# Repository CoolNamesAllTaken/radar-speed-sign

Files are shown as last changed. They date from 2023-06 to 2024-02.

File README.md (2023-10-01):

# radar-speed-sign
How much zoom is too much zoom?

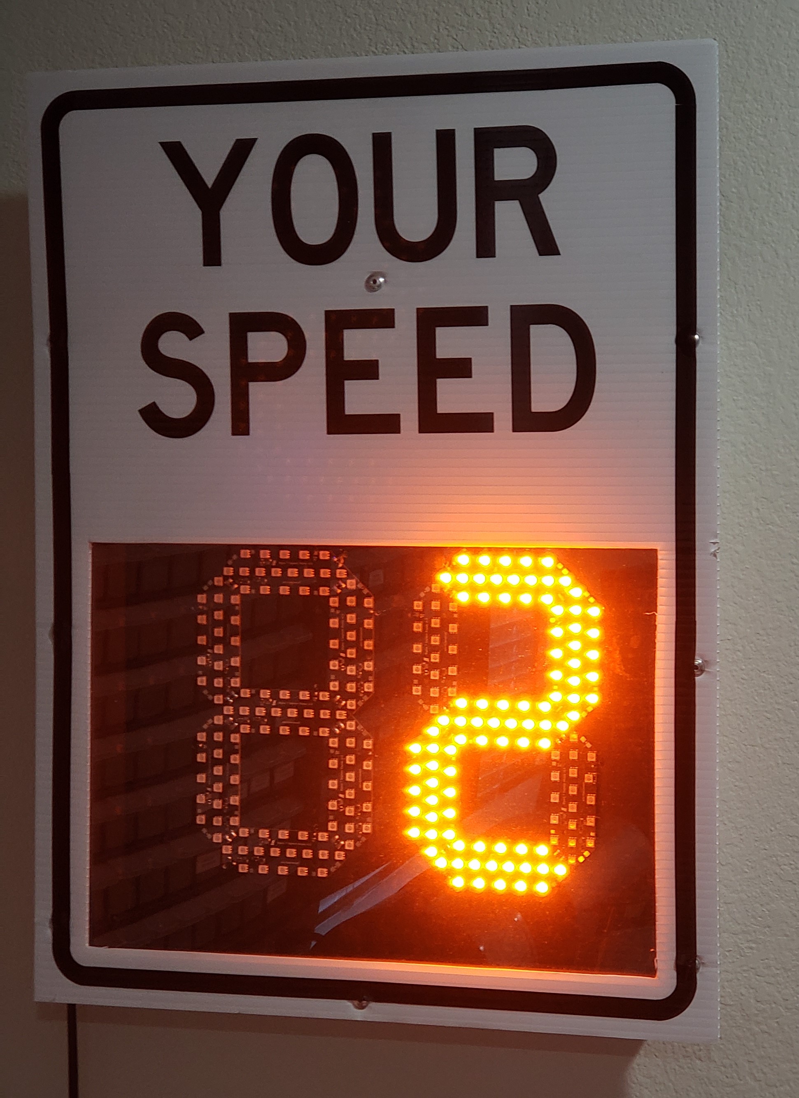
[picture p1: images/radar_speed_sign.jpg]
Radar speed sign mounted to my wall


This is a DIY radar speed sign based on an HB100 doppler radar sensor and a cheap microcontroller (originally an Arduino Nano, now a Pi Pico). The detection range with the stock HB100 antenna is too short for reading speeds of cars, but works well for pedestrians at close range!

This repository includes firmware for both the original project, which used Arduino (C++), and the updated kit version of the project, which runs MicroPython on a Pi Pico. PCB design and fabrication files are also included. Have fun!

[Project Writeup](https://johnmcnelly.com/arduino-radar-speed-sign/)

[Electronics Kit Store Link](https://pantsforbirds.com/product/radar-speed-sign/)

## Software (Python)
Note: Radar speed sign kits ship with a Pi Pico that has been pre-flashed with MicroPython and the latest version of the Pico Radar Speed Sign firmware. Follow the instructions below for updating to new versions of the Pico Radar Speed Sign firmeware or for flashing a Pi Pico from scratch.

### Setting up MicroPython
First time setup with a blank Pi Pico? Follow [these instructions](https://www.raspberrypi.com/documentation/microcontrollers/micropython.html)!

### Updating Firmware
Firmware in the `code/pico_radar_speed_sign` directory can be uploaded to the Pi Pico using Thonny or the [Pico W-Go Extension](https://github.com/paulober/MicroPico) for VSCode. If uploading code using VSCode, open the `code/pico_radar_speed_sign` directory with VSCode in order to automatically use the settings configured in the `.vscode` directory and the `.micropico` file.

## Software (Arduino C++)
The original radar speed sign used code written in Arduino C++. This can be found in the `code/radar_speed_sign` directory, and is intended to be edited using the PlatformIO extension for VSCode.

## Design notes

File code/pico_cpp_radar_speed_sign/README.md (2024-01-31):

# Overview

This folder includes code used for programming the Pi Pico radar speed sign using C++ and the Pico SDK, which enables more advanced functionarlity than can be achieved when programming with MicroPython.

Compilation is done in the included docker environment, and debugging is currently set up to work with a J-Link debugger peripheral via the J-Link GDB Server application.

# Getting Started

1. Initialize git submodules with `git submodule update --recursive --remote`.
2. Build the development docker container with `docker build -t pico_cpp_radar_speed_sign .` from this folder.

### Run the Docker Container

`docker compose up`

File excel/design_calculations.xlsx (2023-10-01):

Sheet: Bigass LED Calculations
Parameter | Value | Unit | Note
5050 LED Module
V_f,LED | 2 | V | Typical forward voltage of LED module.
I_f,LED,channel | 40 | mA | Typical forward current of single channel on LED module with V_f = V_f,LED.
I_f,LED | 120 | mA
Current Limiting Resistor
I_CLR | 120 | mA
V_CLR | 0.5 | V
R_CLR | 4.2 | Ohms
P_CLR,max | 0.1 | W
P_CLR | 0.06 | W | Cross-check power dissipated to make sure It’s within the limit.
NPN Transistor |  |  | https://datasheet.lcsc.com/lcsc/2303221100_Jiangsu-Changjing-Electronics-Technology-Co---Ltd--SS8050_C2150.pdf
I_c | 360 | mA | Collector current from all LED strings.
V_be,sat | 0.8 | V | Base-emitter voltage at I_c. Taken conservatively from datasheet for higher junction temperature.
h_fe | 200 |  | DC Current Gain at I_c.
I_b | 1.8 | mA
V_drive | 3.3 | V | Drive voltage used for speccing base resistor.
R_b | 1.39 | kOhms

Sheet: Pico Board Calculations
Parameter | Value | Unit | Note
V_out | 5 | V
V_fb | 1.23 | V
R_bot | 10 | kOhms |  | V_fb = V_out*(R_bot/(R_bot+R_top))
R_top | 30.7 | kOhms |  | V_fb*(R_bot+R_top) = V_out*R_bot
 |  |  |  | R_top = (V_out-V_fb)*R_bot/V_fb
 |  |  |  | R_top = (V_out/V_fb-1)*R_bot

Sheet: Horn Antenna
Parameter | Value | Units | Note
Near Field
c = f*lambda
d_k | 1 |  | Dielectric constant.
f | 20 | GHz
lambda | 15 | mm | One wavelength. Everything closer than this is pretty much in the near field of the antenna and may affect its tuning.
Nickel Plating Cost Calculator
A_panel | 3232.62 | mm^2 | Surface area of a single side panel.
 | 32.3262 | cm^2
A_total | 258.6096 | cm^2
Plating Thickness | 5 | um
Plating Time | 11.81 | min
Nickel Debits | 473.4388346
One-Plate Solution Volume | 77.86822938 | mL
One-Plate Solution Cost/mL | 0.04755813953
Plating Solution Cost | $3.70

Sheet: Radar Calibration
Parameter | Value | Value | Value | Value | Unit | Note
f | 10.525 | 10.525 | 10.525 | 10.525 | GHz
lambda | 28.50356295 | 28.50356295 | 28.50356295 | 28.50356295 | mm | Wavelength.
V | 1 | 5 | 35 | 95 | mph |  | https://wx.erau.edu/faculty/mullerb/Wx365/Doppler_formulas/doppler_formulas.pdf
V | 0.44704 | 2.2352 | 15.6464 | 42.4688 | m/s
f_d | 31.36730667 | 156.8365333 | 1097.855733 | 2979.894133 | Hz | Doppler shift frequency.

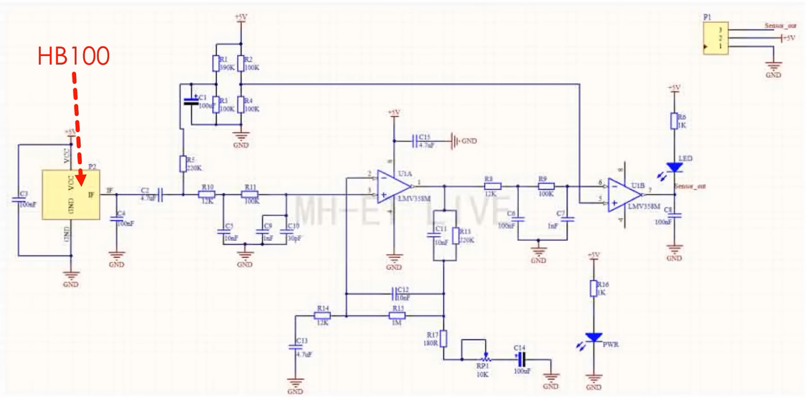
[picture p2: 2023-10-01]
references/HB100X_Schematic_Screenshot.png

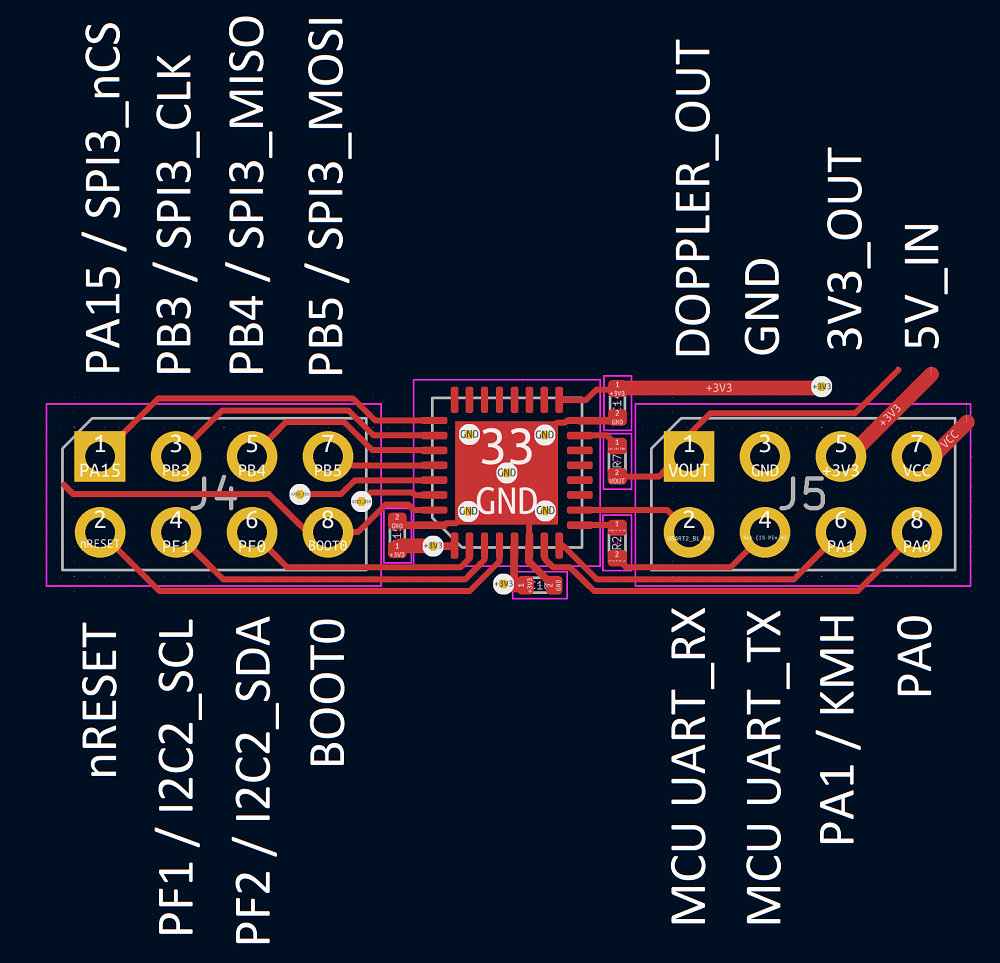
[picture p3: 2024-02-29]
references/CDM324 Doppler Speed Sensor, with FFTs! - Limpkin's blog_files/exp_pinout.png

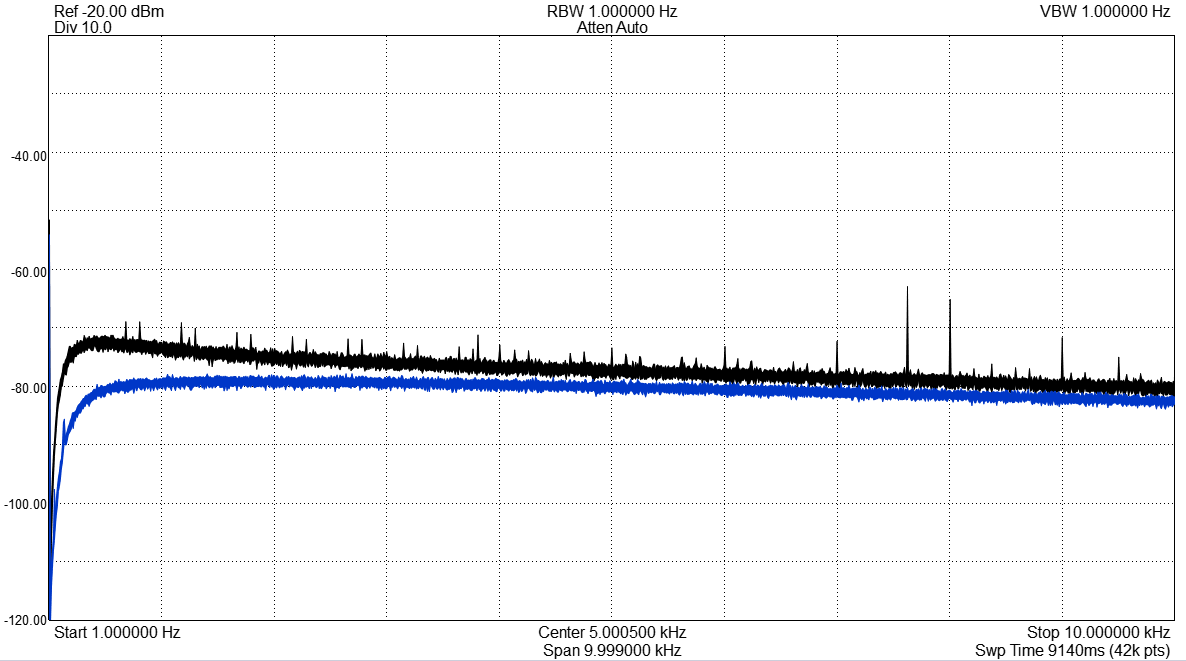
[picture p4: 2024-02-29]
references/CDM324 Doppler Speed Sensor, with FFTs! - Limpkin's blog_files/output_spectrum_with_backpack_50r_vs_sensor.png

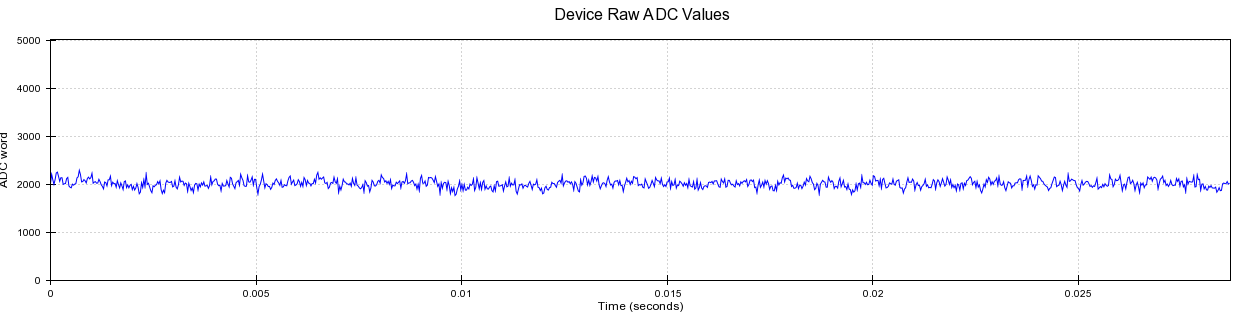
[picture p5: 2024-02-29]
references/CDM324 Doppler Speed Sensor, with FFTs! - Limpkin's blog_files/output_adc_noise_floor.png

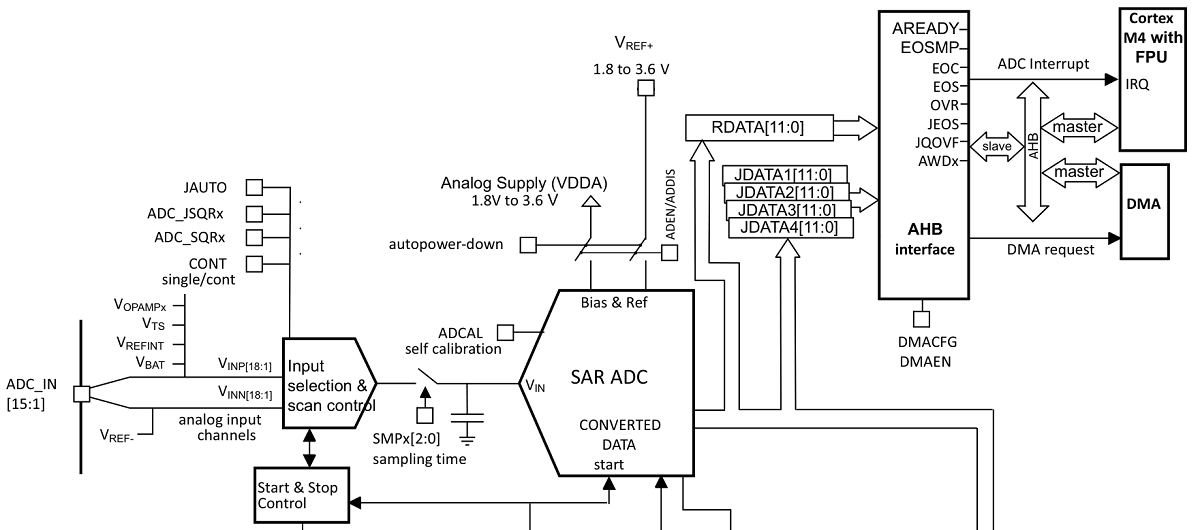
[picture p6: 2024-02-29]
references/CDM324 Doppler Speed Sensor, with FFTs! - Limpkin's blog_files/stm_adc.png

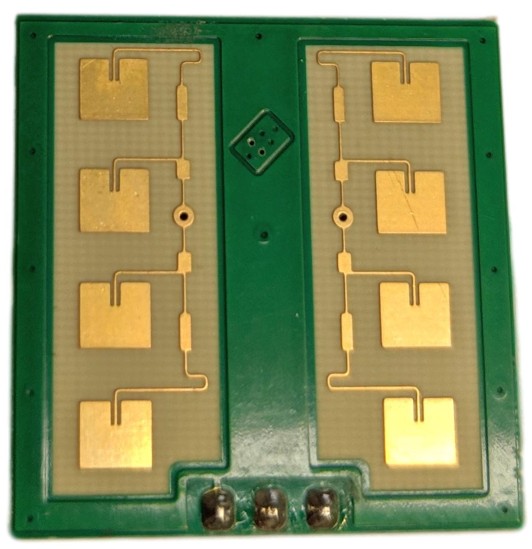
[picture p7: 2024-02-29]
references/Radar Module EIRP Radiation Patterns for RCWL-0516, HB100, CDM324_files/CDM324-Module-PCB.jpg

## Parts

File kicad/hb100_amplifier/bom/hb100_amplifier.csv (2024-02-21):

Reference | Value | Datasheet | Footprint | Qty | DNP | LCSC PN
C1 | 0.1uF | ~ | Capacitor_SMD:C_0603_1608Metric | 1 |  | C1591
C2,C3,C4,C7 | 10uF | ~ | Capacitor_SMD:C_0805_2012Metric | 4 |  | C95841
C5,C9 | 2.2nF | ~ | Capacitor_SMD:C_0603_1608Metric | 2 |  | C16033
C6,C8,C11 | 4.7uF | ~ | Capacitor_SMD:C_0805_2012Metric | 3 |  | C1779
D1 | 1N5819 | ~ | Diode_SMD:D_SOD-123 | 1 |  | C963381
D2 | RED | ~ | LED_SMD:LED_0603_1608Metric | 1 |  | C510027
J1,J2,J3,J4 | 01x02 2.54mm Pin Socket | ~ | Connector_PinSocket_2.54mm:PinSocket_1x02_P2.54mm_Vertical | 4 |  | C49661
J5 | 01x03 2.54mm Pin Header | ~ | Connector_PinHeader_2.54mm:PinHeader_1x03_P2.54mm_Horizontal | 1 |  | C19190476
R1,R7 | 1M | ~ | Resistor_SMD:R_0603_1608Metric | 2 |  | C105578
R2 | 10k | ~ | Resistor_SMD:R_0603_1608Metric | 1 |  | C98220
R3,R4 | 100k | ~ | Resistor_SMD:R_0603_1608Metric | 2 |  | C14675
R5 | 330k | ~ | Resistor_SMD:R_0603_1608Metric | 1 |  | C114618
R6 | 8.2k | ~ | Resistor_SMD:R_0603_1608Metric | 1 |  | C114637
R8 | 0R | ~ | Resistor_SMD:R_0805_2012Metric | 1 |  | C95177
R9 | 12k | ~ | Resistor_SMD:R_0603_1608Metric | 1 |  | C114659
R10 | 287R | ~ | Resistor_SMD:R_0603_1608Metric | 1 |  | C227756
U1 | LMV358 | http://www.ti.com/lit/ds/symlink/lm2904-n.pdf | Package_SO:SOIC-8_3.9x4.9mm_P1.27mm | 1 |  | C63813
U2 | LM1117IMPX-3.3 | https://www.diodes.com/assets/Datasheets/AZ1117.pdf | Package_TO_SOT_SMD:SOT-223-3_TabPin2 | 1 |  | C23984

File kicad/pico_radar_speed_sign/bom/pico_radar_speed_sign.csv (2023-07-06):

Item | Qty | Reference(s) | Value | LibPart | Footprint | Datasheet | LCSC MPN | MPN | REV | Standard Cost
1 | 2 | C1, C2 | 0.1uF | Device:C | Capacitor_SMD:C_0805_2012Metric | https://datasheet.lcsc.com/lcsc/2304140030_Samsung-Electro-Mechanics-CL05B104KO5NNNC_C1525.pdf | C1525 | C49678 | CC0805KRX7R9BB104 | 0.01
2 | 1 | C3 | 680uF 25V | Device:C_Polarized_US | Capacitor_THT:CP_Radial_D10.0mm_P5.00mm | https://datasheet.lcsc.com/lcsc/2304140030_Rubycon-35PX680MEFC10X16_C88725.pdf | C88725 | 35PX680MEFC10X16 |  | 0.12
3 | 1 | C4 | 220uF 25V | Device:C_Polarized_US | Capacitor_THT:CP_Radial_D6.3mm_P2.50mm | https://datasheet.lcsc.com/lcsc/2304140030_Rubycon-25YXJ220M6-3X11_C88729.pdf | C88729 | 25YXJ220M6.3X11 |  | 0.04
4 | 2 | D1, D2 | 40V 3A | Device:D_Schottky | Diode_SMD:D_SMA | https://datasheet.lcsc.com/lcsc/2212271430_SMC-Sangdest-Microelectronicstronic--Nanjing-SK34A_C260394.pdf | C260394 | SK34A |  | 0.07
5 | 2 | J1, J2 | 0.1" Pin Header 02x08 | Connector_Generic:Conn_02x08_Odd_Even | Connector_PinHeader_2.54mm:PinHeader_2x08_P2.54mm_Horizontal | ~ | C492436 | PZ254R-12-16P |  | 0.05
6 | 1 | J3 | 5.08mm Terminal Block 01x02 | Connector_Generic:Conn_01x02 | TerminalBlock_Phoenix:TerminalBlock_Phoenix_MKDS-1,5-2-5.08_1x02_P5.08mm_Horizontal | ~ | C8465 | WJ500V-5.08-2P |  | 0.06
7 | 1 | J4 | 0.1" Pin Header 01x03 | Connector:Conn_01x03_Pin | Connector_PinHeader_2.54mm:PinHeader_1x03_P2.54mm_Horizontal | ~ | C492411 | PZ254R-11-03P |  | 0.01
8 | 1 | J5 | 2.54mm Terminal Block 01x04 | Connector_Generic:Conn_01x04 | TerminalBlock_Phoenix:TerminalBlock_Phoenix_MPT-0,5-4-2.54_1x04_P2.54mm_Horizontal | ~ | C915913 | XY308-2.54-4P |  | 0.21
9 | 1 | L1 | 47uH 3A | Device:L | Custom_Inductor:L_SunItechTech_SLO1040H470MTT | https://datasheet.lcsc.com/lcsc/2209271230_Sunltech-Tech-SLO1040H470MTT_C182153.pdf | C182153 | SLO1040H470MTT |  | 0.13
10 | 2 | PART1, PART2 | 0.1" Pin Socket 01x20 | Custom_Placeholder:Part |  |  | C2897383 | PM254-1-20-Z-8.5 |  | 0.16
11 | 3 | R1, R2, R3 | 10k | Device:R_US | Resistor_SMD:R_0805_2012Metric | ~ | C84376 | RC0805FR-0710KL |  | 0.01
12 | 1 | R4 | 30k 1% | Device:R_US | Resistor_SMD:R_0805_2012Metric | ~ | C126352 | RC0805FR-0730KL |  | 0.01
13 | 1 | R5 | 10k 1% | Device:R_US | Resistor_SMD:R_0805_2012Metric | ~ | C84376 | RC0805FR-0710KL |  | 0.01
14 | 1 | U1 | Pico_H | Custom_MCU:Pico_H | Custom_Module:RPi_Pico_TH_Socket | https://datasheets.raspberrypi.com/pico/pico-datasheet.pdf
15 | 2 | U2, U3 | 74HC595 | 74xx:74HC595 | Package_SO:SOIC-16_3.9x9.9mm_P1.27mm | http://www.ti.com/lit/ds/symlink/sn74hc595.pdf | C5947 | 74HC595D,118 |  | 0.1
16 | 1 | U5 | LM2596S-ADJ | Regulator_Switching:LM2596S-ADJ | Package_TO_SOT_SMD:TO-263-5_TabPin3 | http://www.ti.com/lit/ds/symlink/lm2596.pdf | C347423 | LM2596S-ADJ |  | 0.33

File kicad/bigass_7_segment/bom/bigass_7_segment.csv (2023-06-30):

Item | Qty | Reference(s) | Value | LibPart | Footprint | LCSC_MPN | MPN | REV | Standard Cost
1 | 18 | D1, D2, D3, D4, D5, D6, D7, D8, D9, D10, D11, D12, D14, D15, D16, D17, D18, D19 | LED_RGB | Custom_LED:LED_RGB_AAAKKK | LED_SMD:LED_RGB_5050-6 | C516304 | HL-AF-5060S22OC-3-S1-THL |  | 0.02
2 | 1 | D13 | 40V 1A | Device:D_Schottky | Diode_SMD:D_SOD-323 | C22624 | B5819WS |  | 0.02
3 | 1 | Q3 | 25V 1.5A | Device:Q_NPN_BEC | Package_TO_SOT_SMD:SOT-23 | C181160 | SS8050 |  | 0.01
4 | 1 | R1 | 10k | Device:R_US | Resistor_SMD:R_0805_2012Metric | C84376 | RC0805FR-0710KL |  | 0.01
5 | 1 | R2 | 1.3k | Device:R_US | Resistor_SMD:R_0805_2012Metric | C137582 | RC0805FR-071K3L |  | 0.01
6 | 3 | R3, R4, R5 | 3.9R 0805 1/10W | Device:R_US | Resistor_SMD:R_0805_2012Metric | C137529 | RC0805FR-073R9L |  | 0.01

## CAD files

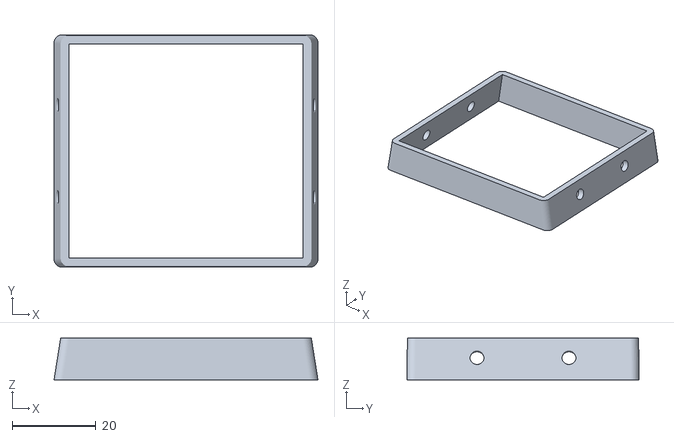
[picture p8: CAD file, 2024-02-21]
solidworks/hb100_horn/fab/back_outer_bracket^hb100_pcb_horn_assy.STL
63.2 x 55.6 x 10.00

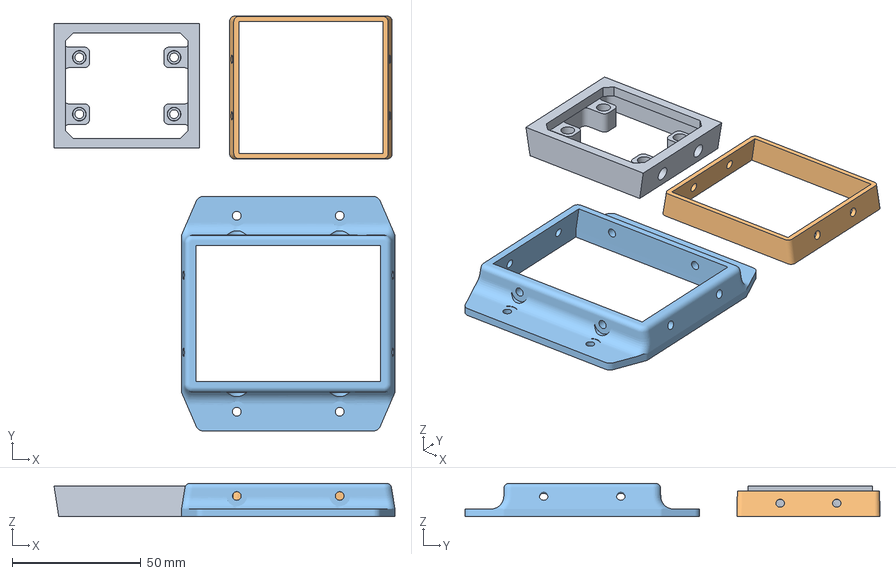
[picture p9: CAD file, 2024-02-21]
solidworks/hb100_horn/fab/back_inner_bracket^hb100_pcb_horn_assy.3mf
132.6 x 161.4 x 13.0 mm
back_inner_bracket^hb100_pcb_horn_assy.STL
back_outer_bracket^hb100_pcb_horn_assy.STL
front_bracket.STL

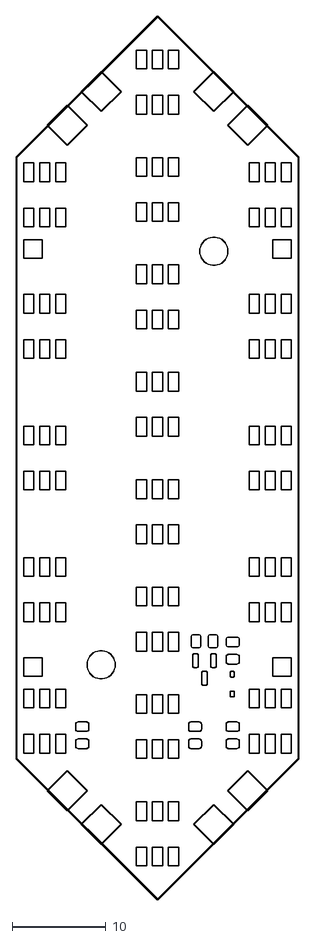
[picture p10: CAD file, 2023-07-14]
kicad/bigass_7_segment/fab/bigass_7_segment-pad_locations.dxf
30.0 x 94.1

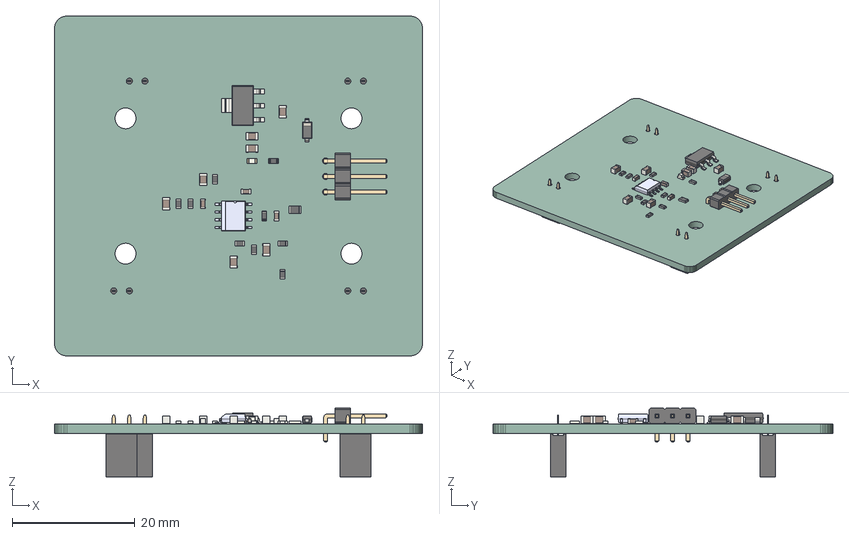
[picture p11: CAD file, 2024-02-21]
kicad/hb100_amplifier/hb100_amplifier.step
60.0 x 55.4 x 11.2 mm
hb100_amplifier PCB

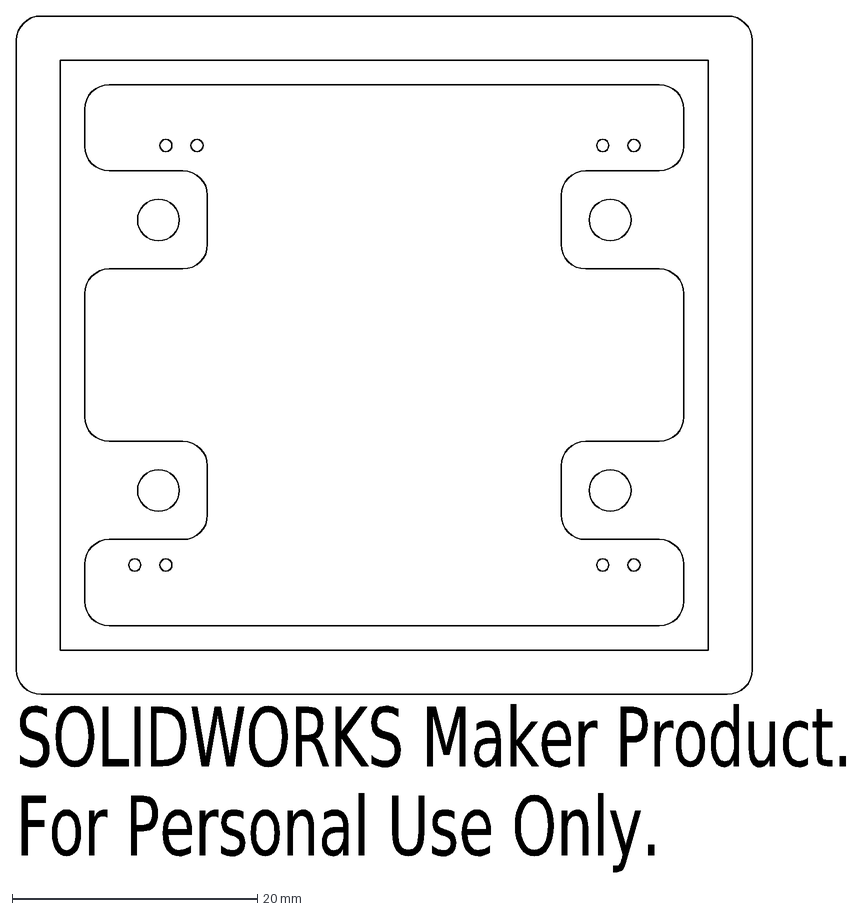
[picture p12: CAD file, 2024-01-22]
solidworks/hb100_horn/dxf/amplifier_pcb_outline.DXF
SOLIDWORKS Maker Product.
For Personal Use Only.

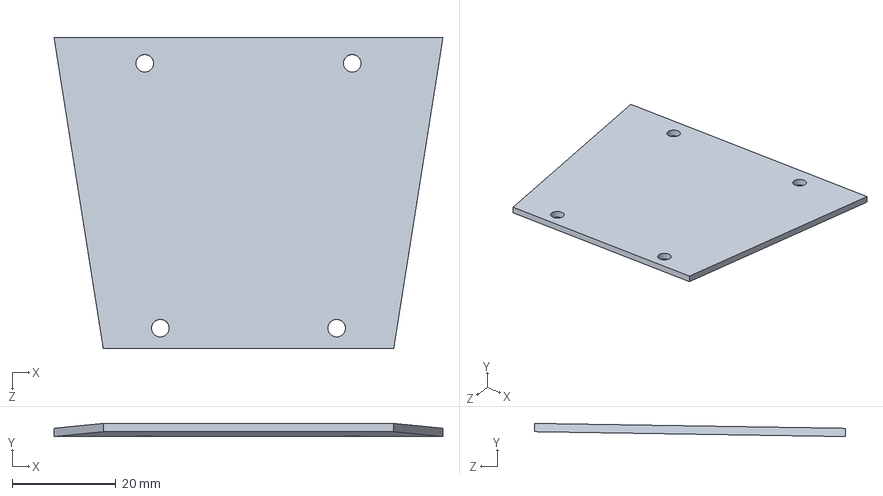
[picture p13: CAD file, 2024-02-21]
solidworks/hb100_horn/horizontal_wall.SLDPRT
75.0 x 2.54 x 60.0 mm

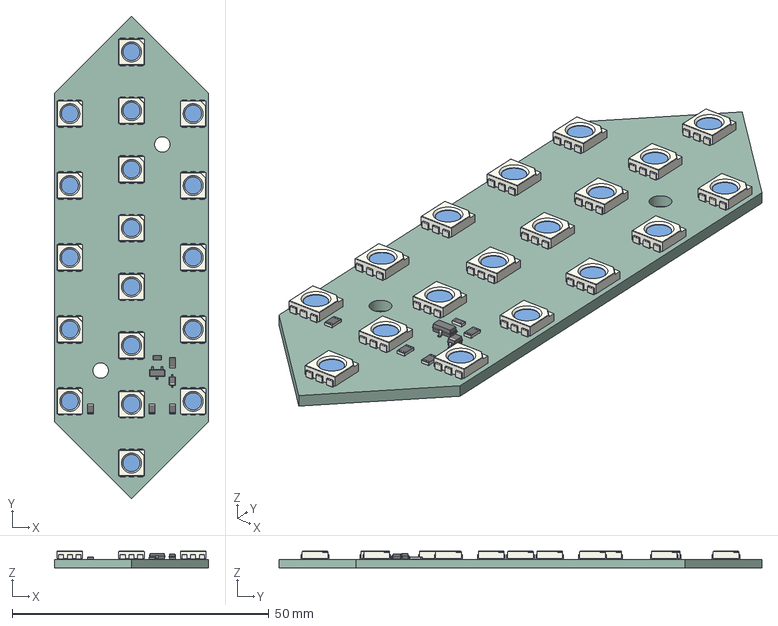
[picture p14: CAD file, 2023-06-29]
kicad/bigass_7_segment/fab/bigass_7_segment.step
30.0 x 94.0 x 3.23 mm
PCB

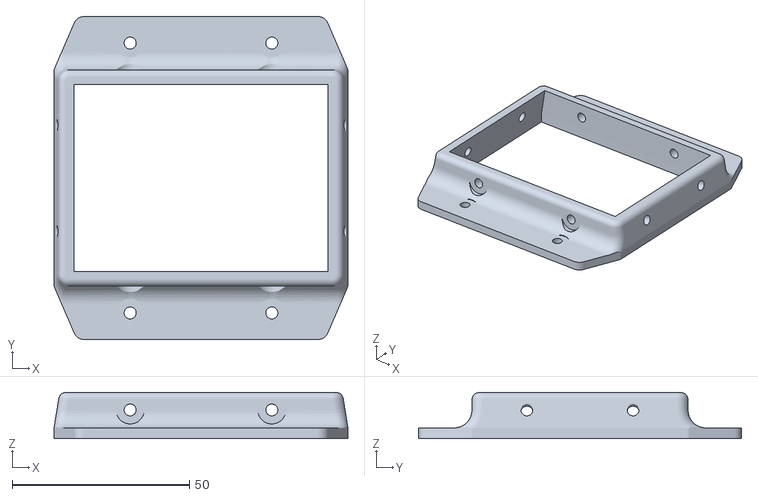
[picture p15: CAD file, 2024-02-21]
solidworks/hb100_horn/fab/front_bracket.STL
83.0 x 91.2 x 13.0

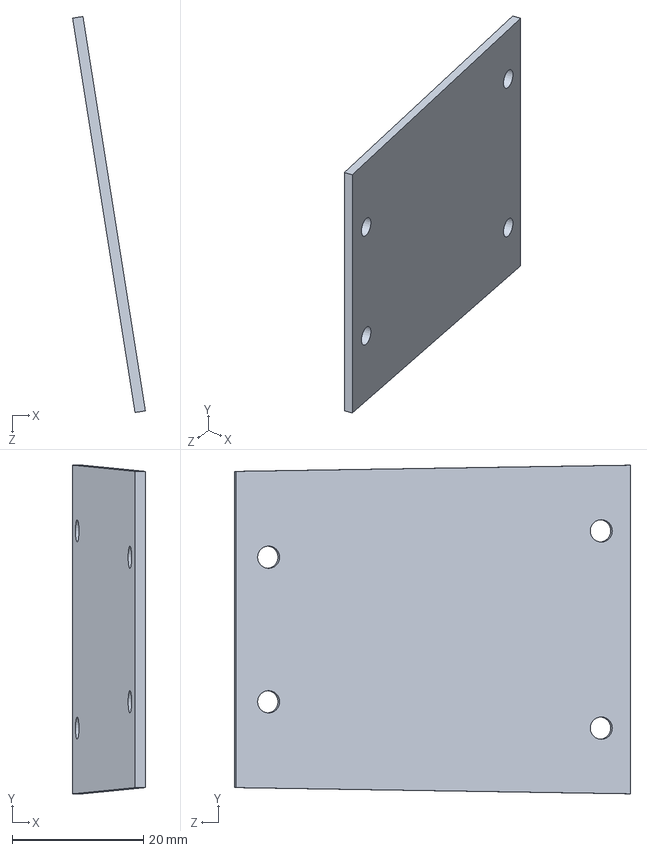
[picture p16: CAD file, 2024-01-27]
solidworks/hb100_horn/side_wall.SLDPRT
11.1 x 50.0 x 60.3 mm

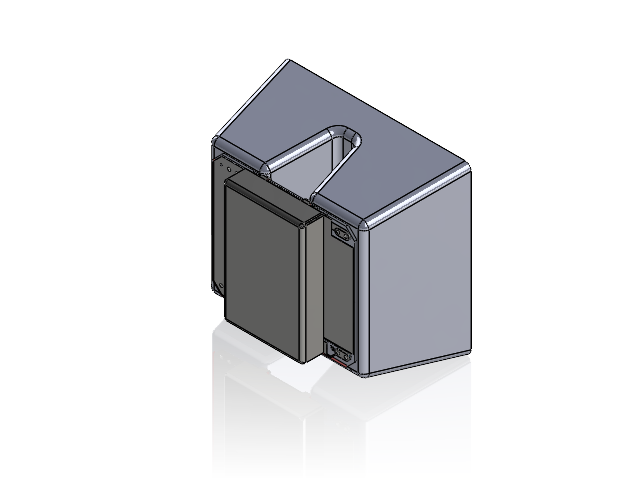
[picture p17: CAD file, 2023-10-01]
solidworks/hb100_horn/hb100_folded_horn_assy.SLDASM
HB100 Miniature Microwave Motion Sensor.step
Part3^hb100_folded_horn_assy

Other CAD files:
solidworks/hb100_horn/front_bracket.SLDPRT
solidworks/hb100_horn/hb100_pcb_horn_skel.SLDPRT
solidworks/hb100_horn/dxf/horizontal_wall.DXF
solidworks/hb100_horn/dxf/side_wall.DXF
solidworks/hb100_horn/fab/back_inner_bracket^hb100_pcb_horn_assy.STL

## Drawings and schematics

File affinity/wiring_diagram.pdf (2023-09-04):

# Pico Radar Speed Sign Wiring Guide v0.1.0

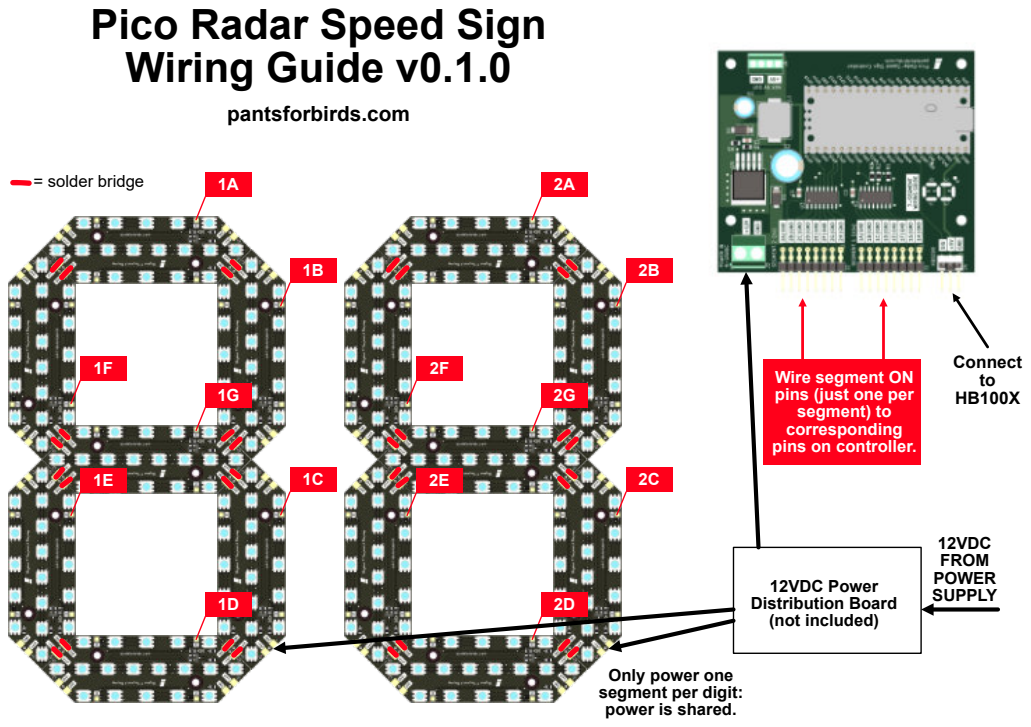
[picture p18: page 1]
= solder bridge; 12VDC Power Distribution Board (not included); 12VDC FROM POWER SUPPLY; pantsforbirds.com; Connect to HB100X

Wire segment ON
pins (just one per
segment) to
corresponding
pins on controller.

Only power one
segment per digit:
power is shared.

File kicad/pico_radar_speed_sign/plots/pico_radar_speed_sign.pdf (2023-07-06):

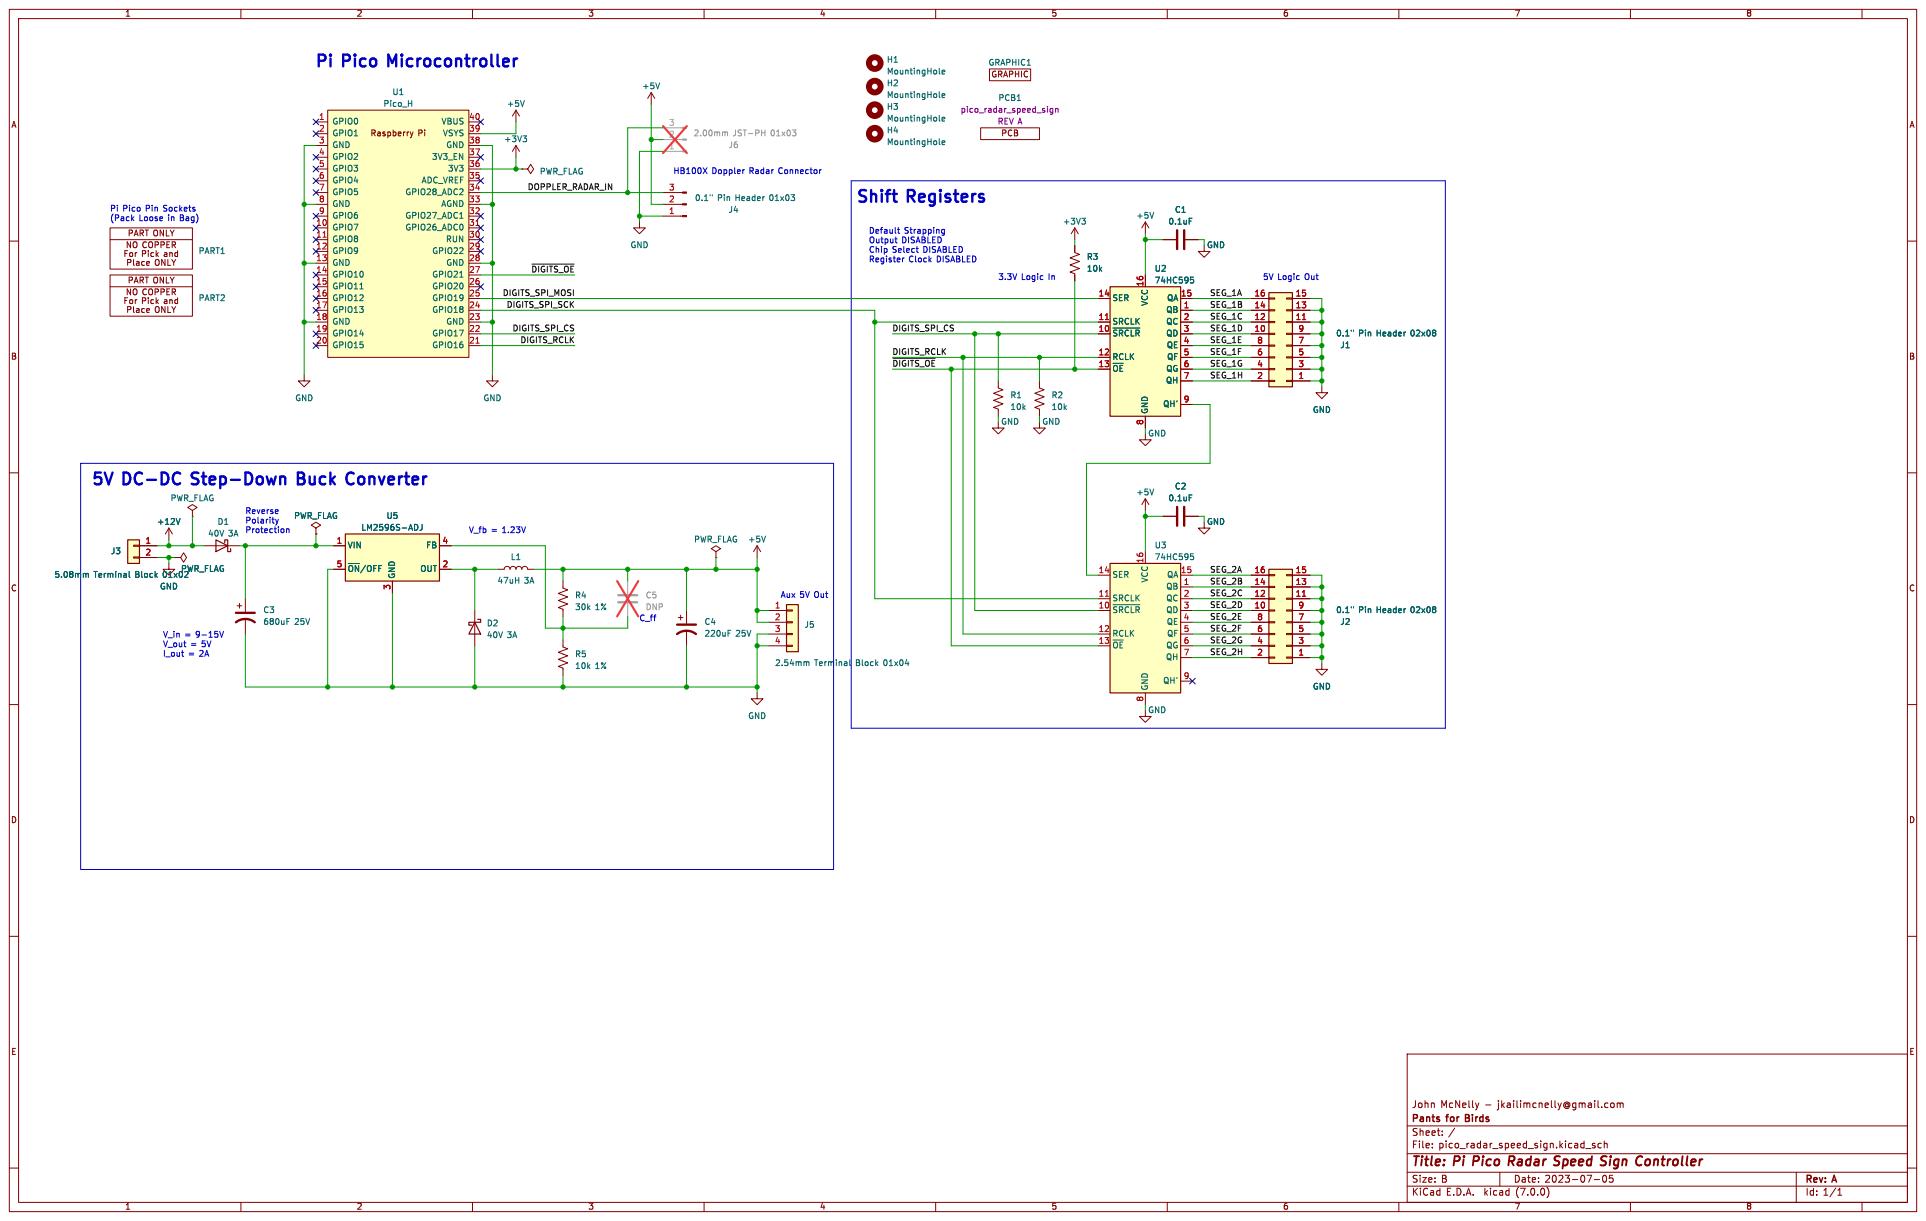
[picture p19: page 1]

3.3V Logic In Pi Pico Microcontroller

Pi Pico Pin Sockets
PART ONLY
For Pick and NO COPPER
Place ONLY

0.1" Pin Header 02x08 GND GND

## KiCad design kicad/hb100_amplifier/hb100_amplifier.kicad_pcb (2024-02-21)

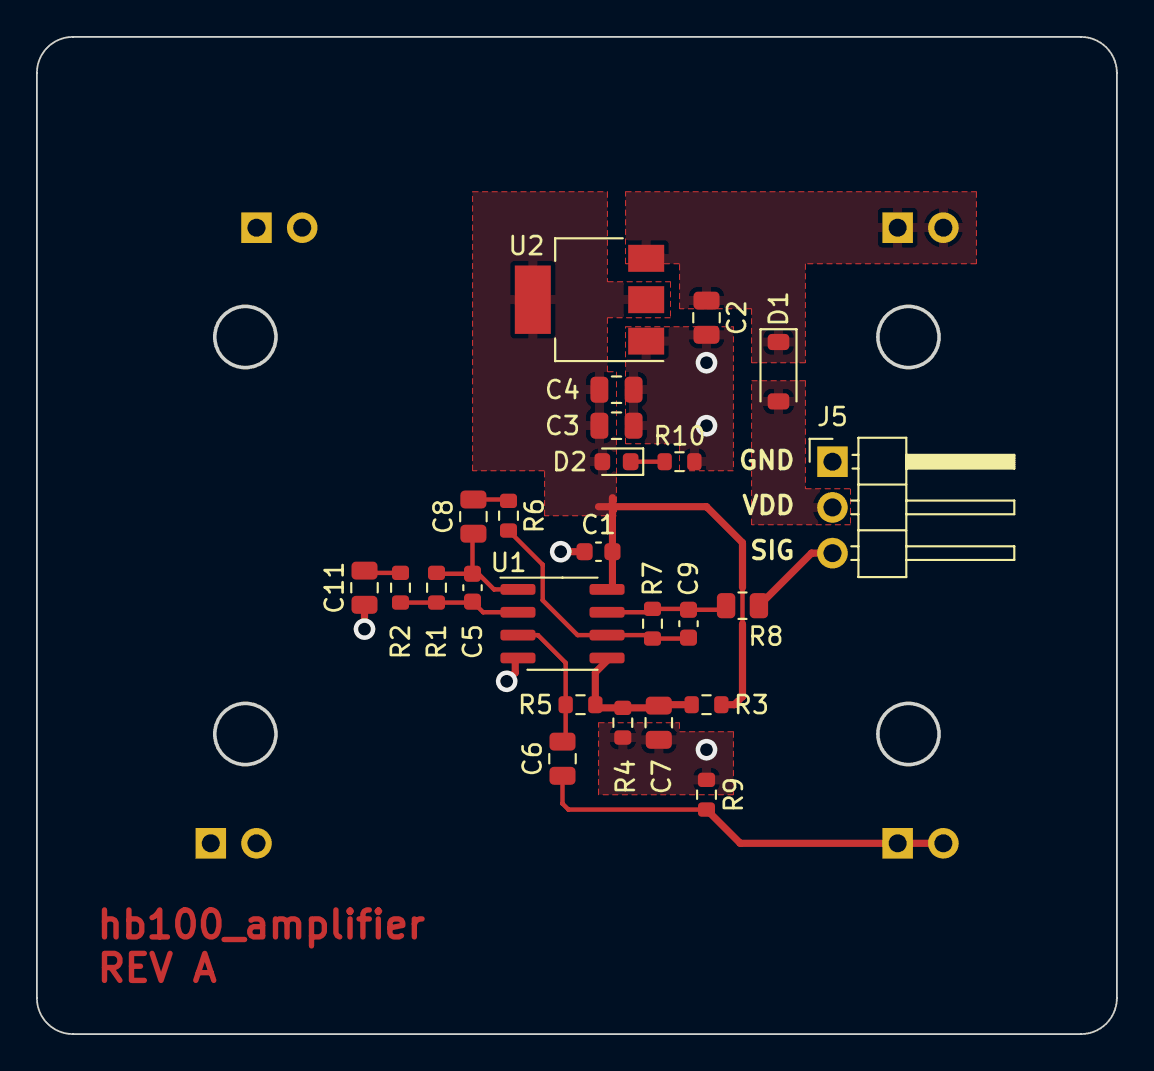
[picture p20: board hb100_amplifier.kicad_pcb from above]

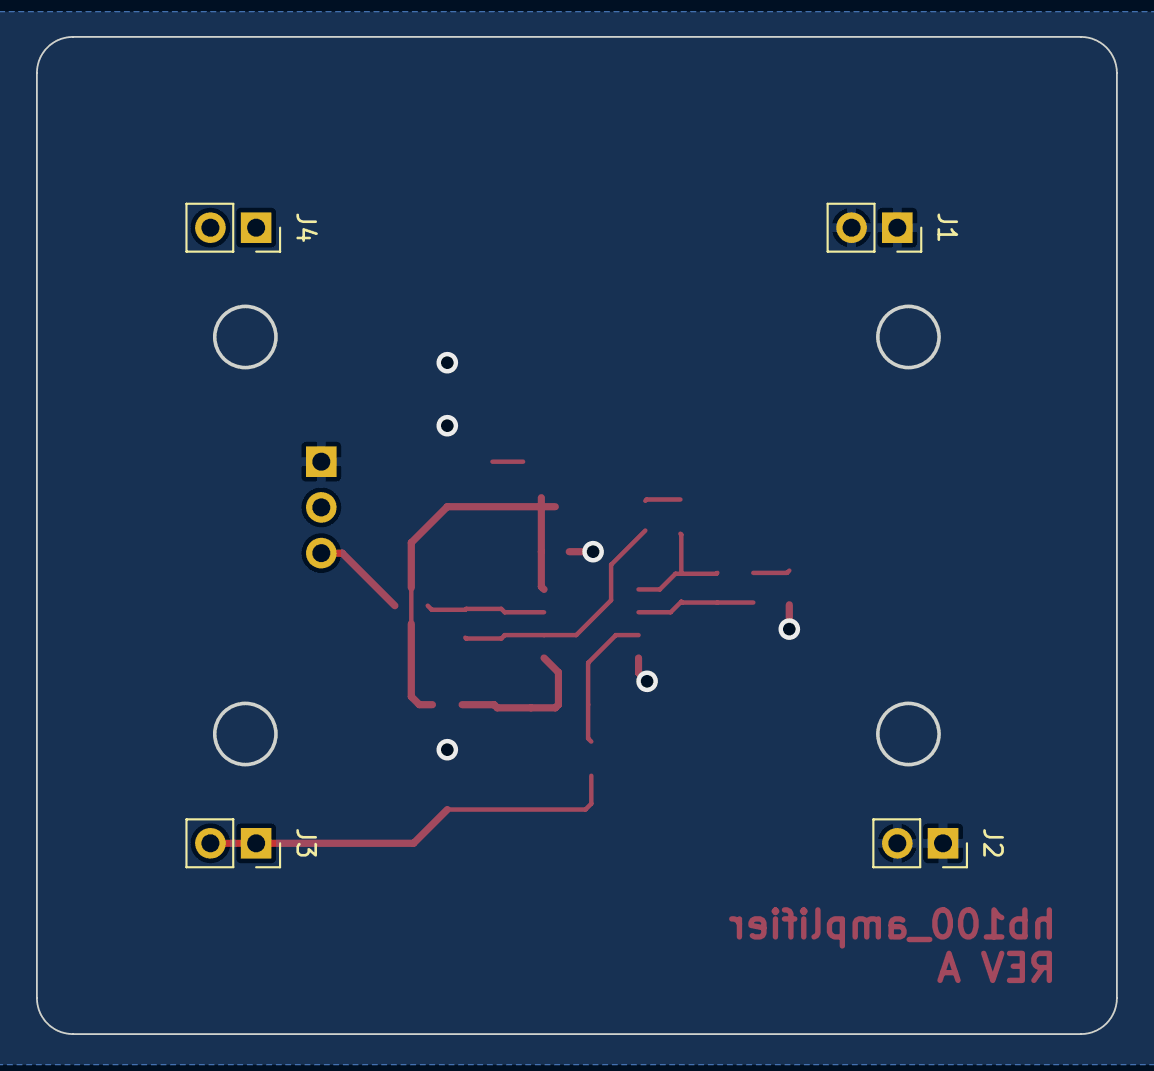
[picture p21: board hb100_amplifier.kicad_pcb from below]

Board: 2 copper layers, 60.0 x 55.4 mm, 29 parts (4 on the bottom side), 15 nets.

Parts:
C1: 0.1uF; C_0603_1608Metric
C2, C3, C4, C7: 10uF; C_0805_2012Metric
C5, C9: 2.2nF; C_0603_1608Metric
C6, C8, C11: 4.7uF; C_0805_2012Metric
D1: 1N5819; D_SOD-123
D2: RED; LED_0603_1608Metric
J1, J2, J3, J4: 01x02 2.54mm Pin Socket; PinSocket_1x02_P2.54mm_Vertical
J5: 01x03 2.54mm Pin Header; PinHeader_1x03_P2.54mm_Horizontal
R1, R7: 1M; R_0603_1608Metric
R2: 10k; R_0603_1608Metric
R3, R4: 100k; R_0603_1608Metric
R5: 330k; R_0603_1608Metric
R6: 8.2k; R_0603_1608Metric
R8: 0R; R_0805_2012Metric
R9: 12k; R_0603_1608Metric
R10: 287R; R_0603_1608Metric
U1: LMV358; SOIC-8_3.9x4.9mm_P1.27mm
U2: LM1117IMPX-3.3; SOT-223-3_TabPin2

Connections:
+3V3: C1.1, C3.1, C4.1, D2.2 (A), R3.1, U1.8 (V+), U2.2 (VO)
+5V: C2.1, D1.1 (K), J4.1, J4.2, U2.3 (VI)
/BIAS_1V65: C7.1, R3.2, R4.1, R5.1, U1.5 (+)
/HB100_OUT: C6.1, J3.1, J3.2, R9.1
/OP1_IN: C6.2, R5.2, U1.3 (+)
/OP1_OUT: C5.2, C8.1, R1.2, U1.1
/OP2_IN: C9.1, R6.2, R7.1, U1.6 (-)
/OP2_OUT: C9.2, R7.2, R8.1, U1.7
/PWM_OUT: J5.3, R8.2
GND: C1.2, C2.2, C3.2, C4.2, C7.2, C11.1, J1.1, J1.2, J2.1, J2.2, J5.1, R4.2, R9.2, R10.2, U1.4 (V-), U2.1 (GND)
unnamed: C8.2, R6.1
unnamed: C11.2, R2.2
unnamed: D2.1 (K), R10.1
unnamed: C5.1, R1.1, R2.1, U1.2 (-)
VDD: D1.2 (A), J5.2

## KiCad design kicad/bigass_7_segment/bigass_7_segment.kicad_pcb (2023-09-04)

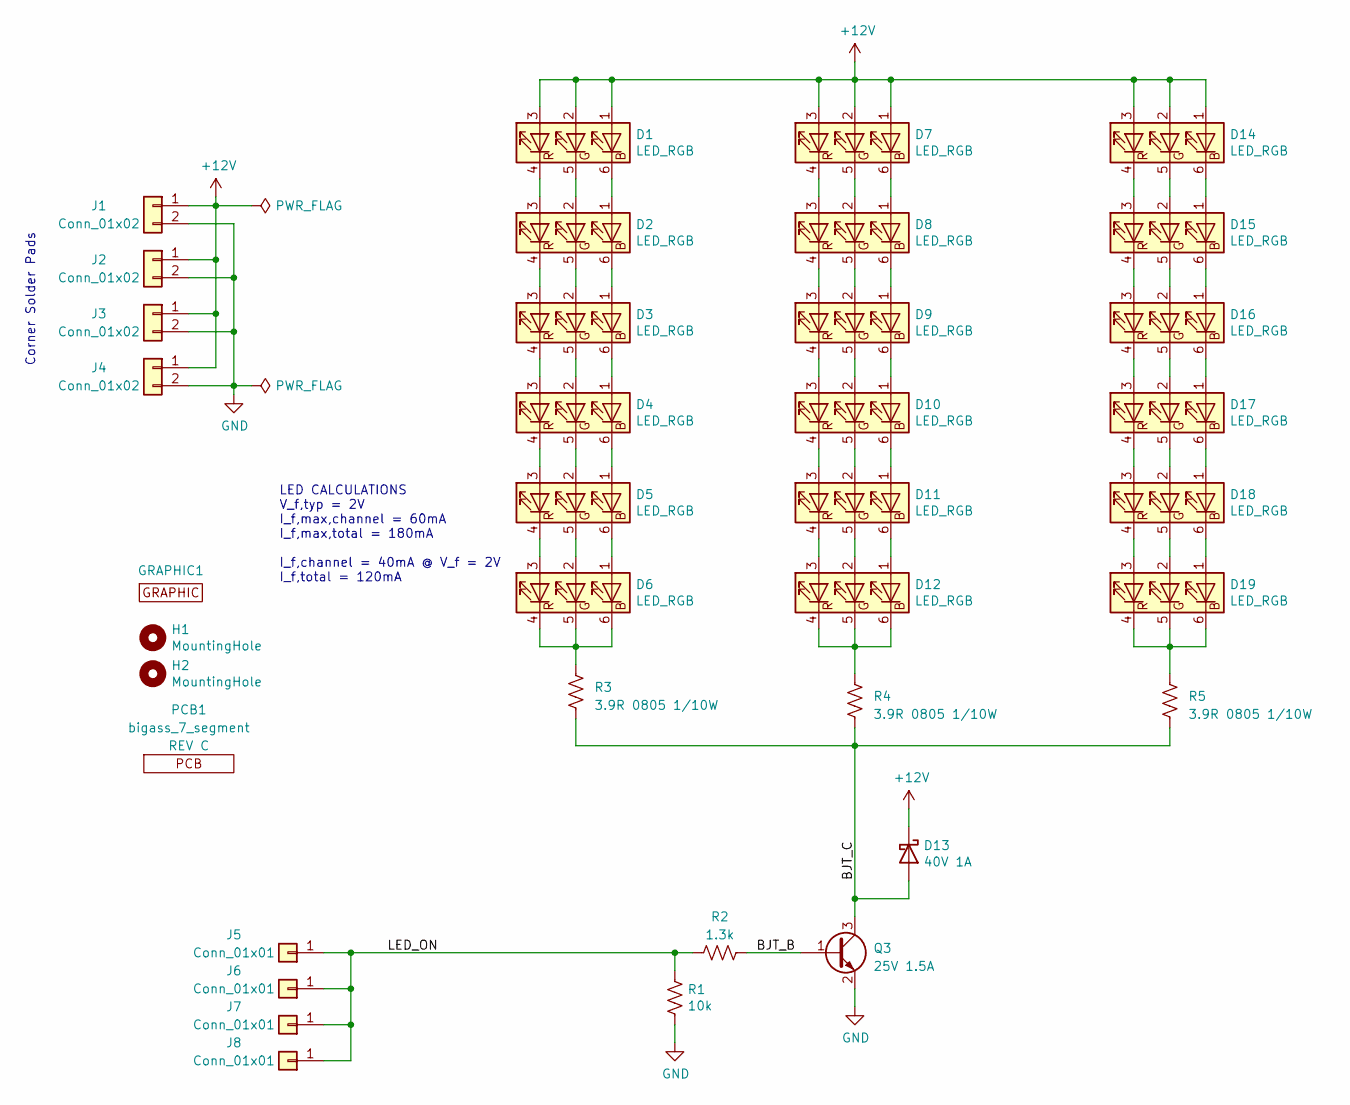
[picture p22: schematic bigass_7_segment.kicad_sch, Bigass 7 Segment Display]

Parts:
D1, D2, D3, D4, D5, D6, D7, D8, D9, D10, D11, D12, D14, D15, D16, D17, D18, D19: LED_RGB; LED_RGB_5050-6; MPN HL-AF-5060S22OC-3-S1-THL; LCSC_MPN C516304
D13: 40V 1A; D_SOD-323; MPN B5819WS; LCSC_MPN C22624
GRAPHIC1: Graphic; BirdWithPants_Small_Right
H1, H2: MountingHole; MountingHole_3.2mm_M3_Isolated
J1, J2, J3, J4: Conn_01x02; Pad_01x02_Edge_Pair
J5, J6, J7, J8: Conn_01x01; TestPoint_Pad_2.0x2.0mm
PCB1: PCB; PCB_PN_REV_Small; MPN bigass_7_segment
Q3: 25V 1.5A; SOT-23; MPN SS8050; LCSC_MPN C181160
R1: 10k; R_0805_2012Metric; MPN RC0805FR-0710KL; LCSC_MPN C84376
R2: 1.3k; R_0805_2012Metric; MPN RC0805FR-071K3L; LCSC_MPN C137582
R3, R4, R5: 3.9R 0805 1/10W; R_0805_2012Metric; MPN RC0805FR-073R9L; LCSC_MPN C137529

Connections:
+12V: D1.1 (BA), D1.2 (GA), D1.3 (RA), D7.1 (BA), D7.2 (GA), D7.3 (RA), D13.1 (K), D14.1 (BA), D14.2 (GA), D14.3 (RA), J1.1, J2.1, J3.1, J4.1
/BJT_B: Q3.1 (B), R2.2
/BJT_C: D13.2 (A), Q3.3 (C), R3.2, R4.2, R5.2
/LED_ON: J5.1, J6.1, J7.1, J8.1, R1.1, R2.1
GND: J1.2, J2.2, J3.2, J4.2, Q3.2 (E), R1.2
unnamed: D1.6 (BK), D2.1 (BA)
unnamed: D1.5 (GK), D2.2 (GA)
unnamed: D1.4 (RK), D2.3 (RA)
unnamed: D2.6 (BK), D3.1 (BA)
unnamed: D2.5 (GK), D3.2 (GA)
unnamed: D2.4 (RK), D3.3 (RA)
unnamed: D3.6 (BK), D4.1 (BA)
unnamed: D3.5 (GK), D4.2 (GA)
unnamed: D3.4 (RK), D4.3 (RA)
unnamed: D4.6 (BK), D5.1 (BA)
unnamed: D4.5 (GK), D5.2 (GA)
unnamed: D4.4 (RK), D5.3 (RA)
unnamed: D5.6 (BK), D6.1 (BA)
unnamed: D5.5 (GK), D6.2 (GA)
unnamed: D5.4 (RK), D6.3 (RA)
unnamed: D6.4 (RK), D6.5 (GK), D6.6 (BK), R3.1
unnamed: D7.6 (BK), D8.1 (BA)
unnamed: D7.5 (GK), D8.2 (GA)
unnamed: D7.4 (RK), D8.3 (RA)
unnamed: D8.6 (BK), D9.1 (BA)
unnamed: D8.5 (GK), D9.2 (GA)
unnamed: D8.4 (RK), D9.3 (RA)
unnamed: D9.6 (BK), D10.1 (BA)
unnamed: D10.6 (BK), D11.1 (BA)
unnamed: D9.5 (GK), D10.2 (GA)
unnamed: D10.5 (GK), D11.2 (GA)
unnamed: D9.4 (RK), D10.3 (RA)
unnamed: D10.4 (RK), D11.3 (RA)
unnamed: D11.6 (BK), D12.1 (BA)
unnamed: D11.5 (GK), D12.2 (GA)
unnamed: D11.4 (RK), D12.3 (RA)
unnamed: D12.4 (RK), D12.5 (GK), D12.6 (BK), R4.1
unnamed: D14.6 (BK), D15.1 (BA)
unnamed: D14.5 (GK), D15.2 (GA)
unnamed: D14.4 (RK), D15.3 (RA)
unnamed: D15.6 (BK), D16.1 (BA)
unnamed: D15.5 (GK), D16.2 (GA)
unnamed: D15.4 (RK), D16.3 (RA)
unnamed: D16.6 (BK), D17.1 (BA)
unnamed: D16.5 (GK), D17.2 (GA)
unnamed: D16.4 (RK), D17.3 (RA)
unnamed: D17.6 (BK), D18.1 (BA)
unnamed: D17.5 (GK), D18.2 (GA)
unnamed: D17.4 (RK), D18.3 (RA)
unnamed: D18.6 (BK), D19.1 (BA)
unnamed: D18.5 (GK), D19.2 (GA)
unnamed: D18.4 (RK), D19.3 (RA)
unnamed: D19.4 (RK), D19.5 (GK), D19.6 (BK), R5.1

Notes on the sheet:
LED CALCULATIONS V_f,typ = 2V I_f,max,channel = 60mA I_f,max,total = 180mA I_f,channel = 40mA @ V_f = 2V I_f,total = 120mA
Corner Solder Pads

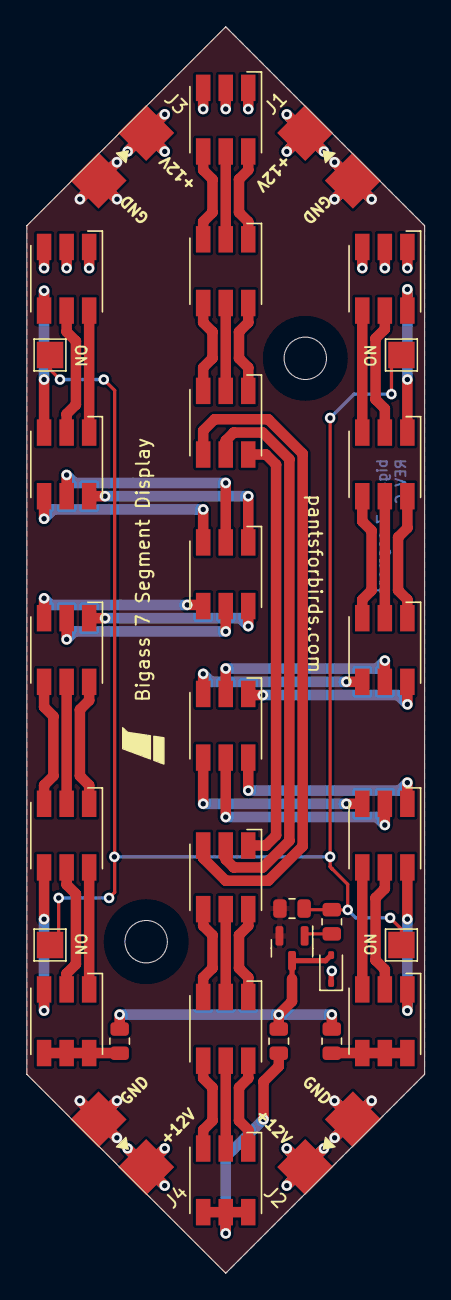
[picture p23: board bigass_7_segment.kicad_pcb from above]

Board: 2 copper layers, 30.0 x 94.0 mm, 37 parts (1 on the bottom side), 53 nets.

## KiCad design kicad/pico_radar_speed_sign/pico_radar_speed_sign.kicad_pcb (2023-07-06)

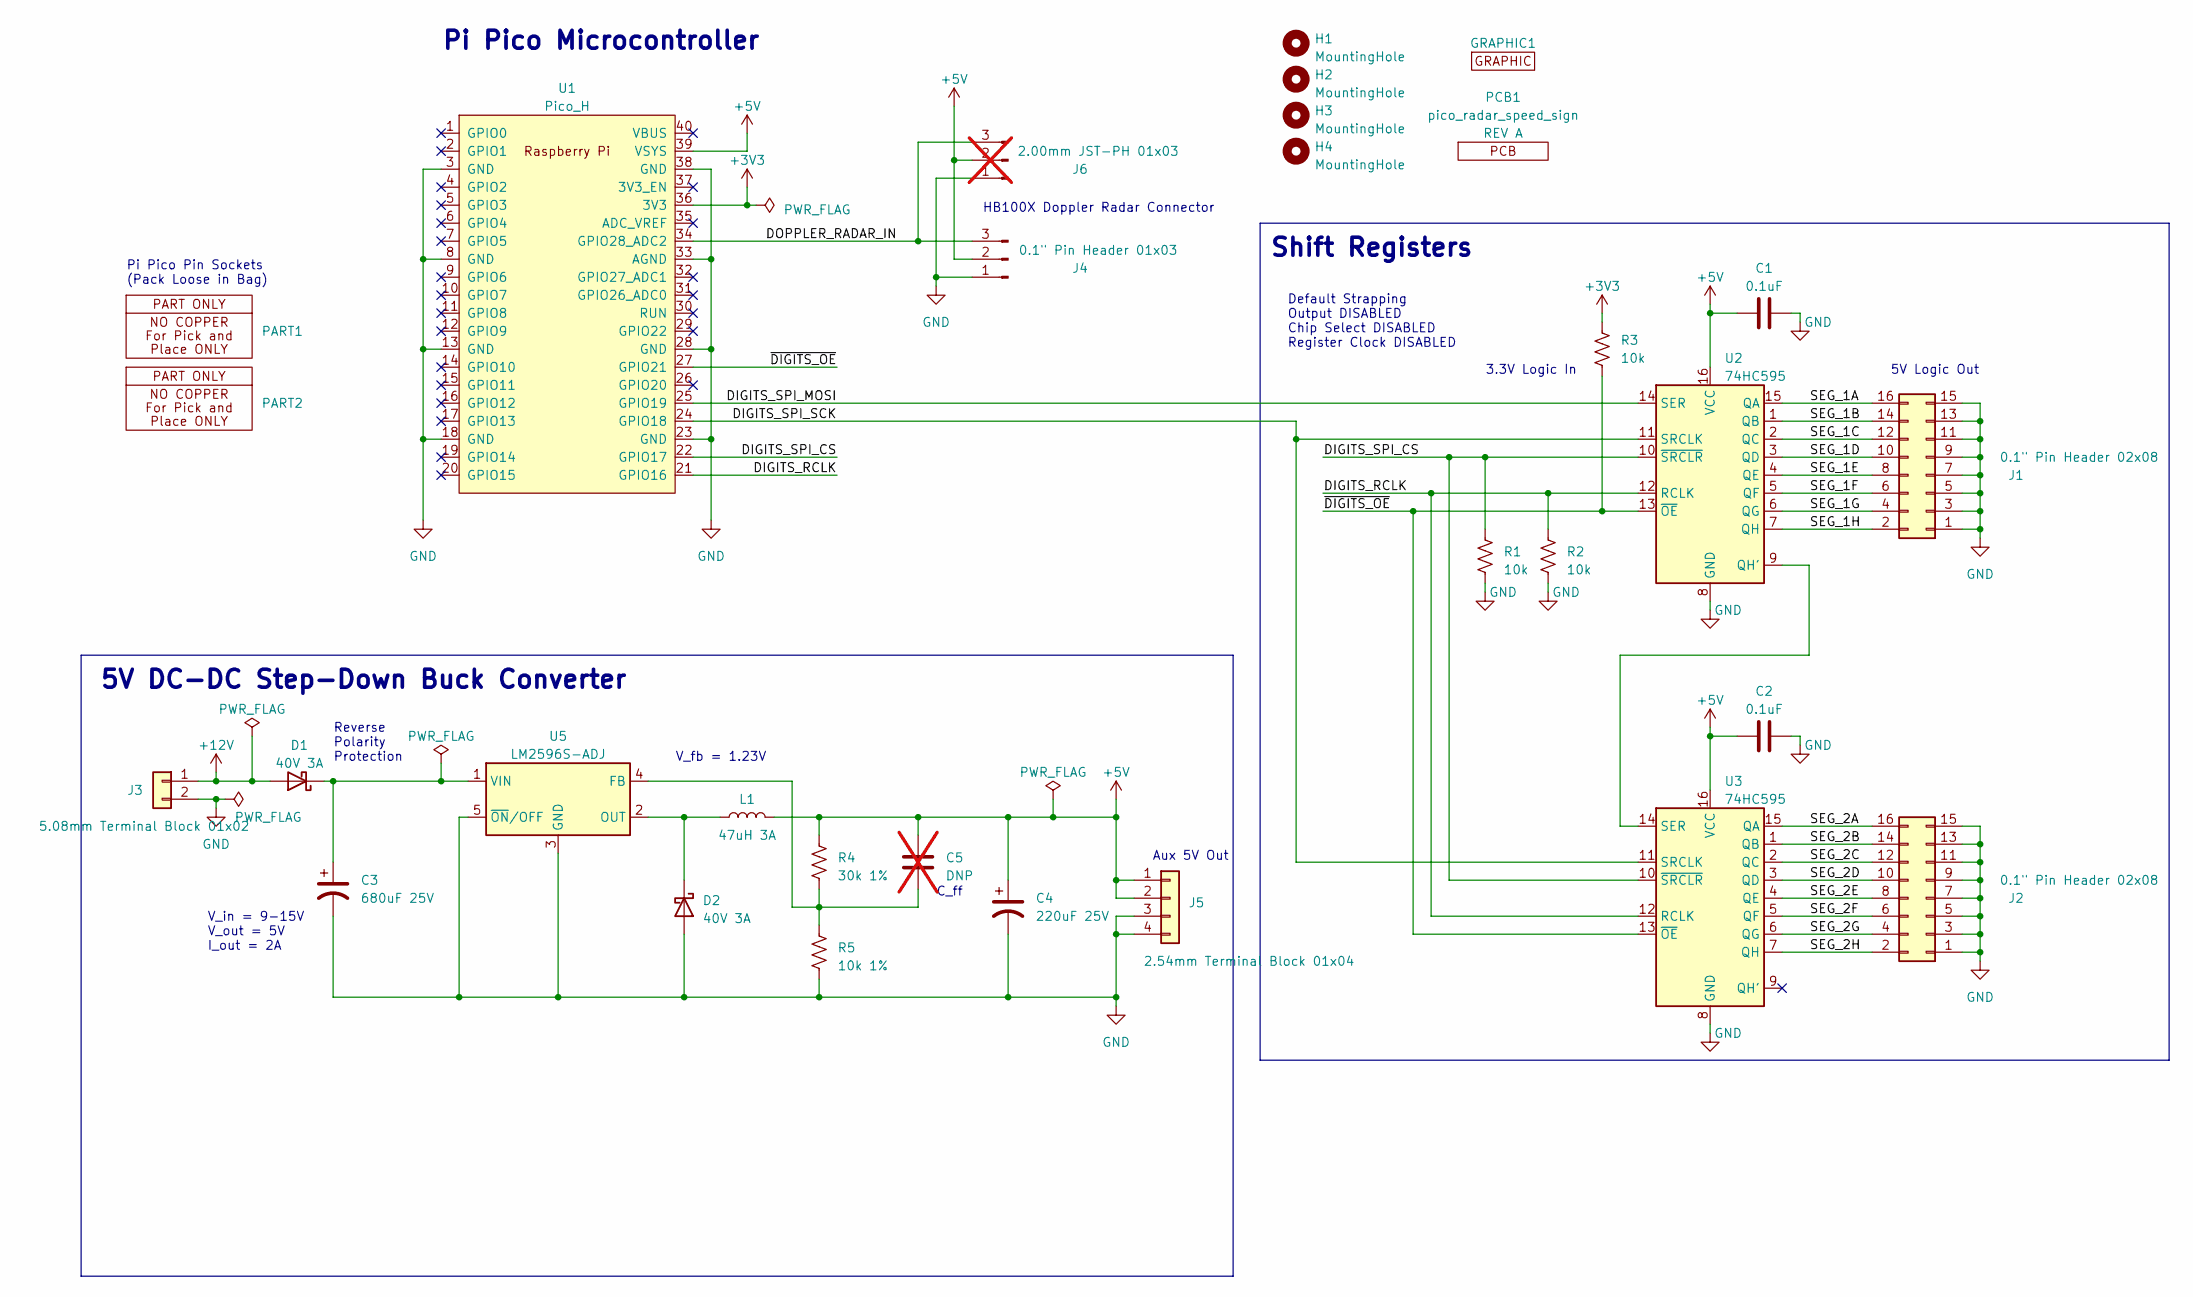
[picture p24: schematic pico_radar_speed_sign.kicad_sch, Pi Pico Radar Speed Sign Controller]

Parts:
C1, C2: 0.1uF; C_0805_2012Metric; MPN CC0805KRX7R9BB104; LCSC MPN C49678
C3: 680uF 25V; CP_Radial_D10.0mm_P5.00mm; MPN 35PX680MEFC10X16; LCSC MPN C88725
C4: 220uF 25V; CP_Radial_D6.3mm_P2.50mm; MPN 25YXJ220M6.3X11; LCSC MPN C88729
C5: DNP; C_0805_2012Metric; not fitted
D1, D2: 40V 3A; D_SMA; MPN SK34A; LCSC MPN C260394
GRAPHIC1: Graphic; BirdWithPants_Small_Right
H1, H2, H3, H4: MountingHole; MountingHole_3.2mm_M3
J1, J2: 0.1" Pin Header 02x08; PinHeader_2x08_P2.54mm_Horizontal; MPN PZ254R-12-16P; LCSC MPN C492436
J3: 5.08mm Terminal Block 01x02; TerminalBlock_Phoenix_MKDS-1,5-2-5.08_1x02_P5.08mm_Horizont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; MPN WJ500V-5.08-2P; LCSC MPN C8465
J4: 0.1" Pin Header 01x03; PinHeader_1x03_P2.54mm_Horizontal; MPN PZ254R-11-03P; LCSC MPN C492411
J5: 2.54mm Terminal Block 01x04; TerminalBlock_Phoenix_MPT-0,5-4-2.54_1x04_P2.54mm_Horizontal; MPN XY308-2.54-4P; LCSC MPN C915913
J6: 2.00mm JST-PH 01x03; JST_PH_B3B-PH-K_1x03_P2.00mm_Vertical; not fitted
L1: 47uH 3A; L_SunItechTech_SLO1040H470MTT; MPN SLO1040H470MTT; LCSC MPN C182153
PART1, PART2: 0.1" Pin Socket 01x20; MPN PM254-1-20-Z-8.5; LCSC MPN C2897383
PCB1: PCB; PCB_PN_REV; MPN pico_radar_speed_sign
R1, R2, R3: 10k; R_0805_2012Metric; MPN RC0805FR-0710KL; LCSC MPN C84376
R4: 30k 1%; R_0805_2012Metric; MPN RC0805FR-0730KL; LCSC MPN C126352
R5: 10k 1%; R_0805_2012Metric; MPN RC0805FR-0710KL; LCSC MPN C84376
U1: Pico_H; RPi_Pico_TH_Socket; MPN SC0917
U2, U3: 74HC595; SOIC-16_3.9x9.9mm_P1.27mm; MPN 74HC595D,118; LCSC MPN C5947
U5: LM2596S-ADJ; TO-263-5_TabPin3; MPN LM2596S-ADJ; LCSC MPN C347423

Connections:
+3V3: R3.1, U1.36 (3V3)
+5V: C1.1, C2.1, C4.1, C5.1, J4.2, J5.1, J5.2, J6.2, L1.2, R4.1, U1.39 (VSYS), U2.16 (VCC), U3.16 (VCC)
+12V: D1.2 (A), J3.1
/DIGITS_RCLK: R2.1, U1.21 (GPIO16), U2.12 (RCLK), U3.12 (RCLK)
/DIGITS_SPI_CS: R1.1, U1.22 (GPIO17), U2.10 (~SRCLR), U3.10 (~SRCLR)
/DIGITS_SPI_MOSI: U1.25 (GPIO19), U2.14 (SER)
/DIGITS_SPI_SCK: U1.24 (GPIO18), U2.11 (SRCLK), U3.11 (SRCLK)
/DOPPLER_RADAR_IN: J4.3, J6.3, U1.34 (GPIO28_ADC2)
/SEG_1A: J1.16, U2.15 (QA)
/SEG_1B: J1.14, U2.1 (QB)
/SEG_1C: J1.12, U2.2 (QC)
/SEG_1D: J1.10, U2.3 (QD)
/SEG_1E: J1.8, U2.4 (QE)
/SEG_1F: J1.6, U2.5 (QF)
/SEG_1G: J1.4, U2.6 (QG)
/SEG_1H: J1.2, U2.7 (QH)
/SEG_2A: J2.16, U3.15 (QA)
/SEG_2B: J2.14, U3.1 (QB)
/SEG_2C: J2.12, U3.2 (QC)
/SEG_2D: J2.10, U3.3 (QD)
/SEG_2E: J2.8, U3.4 (QE)
/SEG_2F: J2.6, U3.5 (QF)
/SEG_2G: J2.4, U3.6 (QG)
/SEG_2H: J2.2, U3.7 (QH)
/~DIGITS_OE: R3.2, U1.27 (GPIO21), U2.13 (~OE), U3.13 (~OE)
GND: C1.2, C2.2, C3.2, C4.2, D2.2 (A), J1.1, J1.3, J1.5, J1.7, J1.9, J1.11, J1.13, J1.15, J2.1, J2.3, J2.5, J2.7, J2.9, J2.11, J2.13, J2.15, J3.2, J4.1, J5.3, J5.4, J6.1, R1.2, R2.2, R5.2, U1.3 (GND), U1.8 (GND), U1.13 (GND), U1.18 (GND), U1.23 (GND), U1.28 (GND), U1.33 (AGND), U1.38 (GND), U2.8 (GND), U3.8 (GND), U5.3 (GND), U5.5 (~ON/OFF)
unnamed: C3.1, D1.1 (K), U5.1 (VIN)
unnamed: D2.1 (K), L1.1, U5.2 (OUT)
unnamed: U2.9 (QH'), U3.14 (SER)
unnamed: C5.2, R4.2, R5.1, U5.4 (FB)

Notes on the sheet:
3.3V Logic In
Pi Pico Pin Sockets (Pack Loose in Bag)
HB100X Doppler Radar Connector
C_ff
Aux 5V Out
5V DC-DC Step-Down Buck Converter
V_in = 9-15V V_out = 5V I_out = 2A
5V Logic Out
Default Strapping Output DISABLED Chip Select DISABLED Register Clock DISABLED
Pi Pico Microcontroller
V_fb = 1.23V
Reverse Polarity Protection
Shift Registers

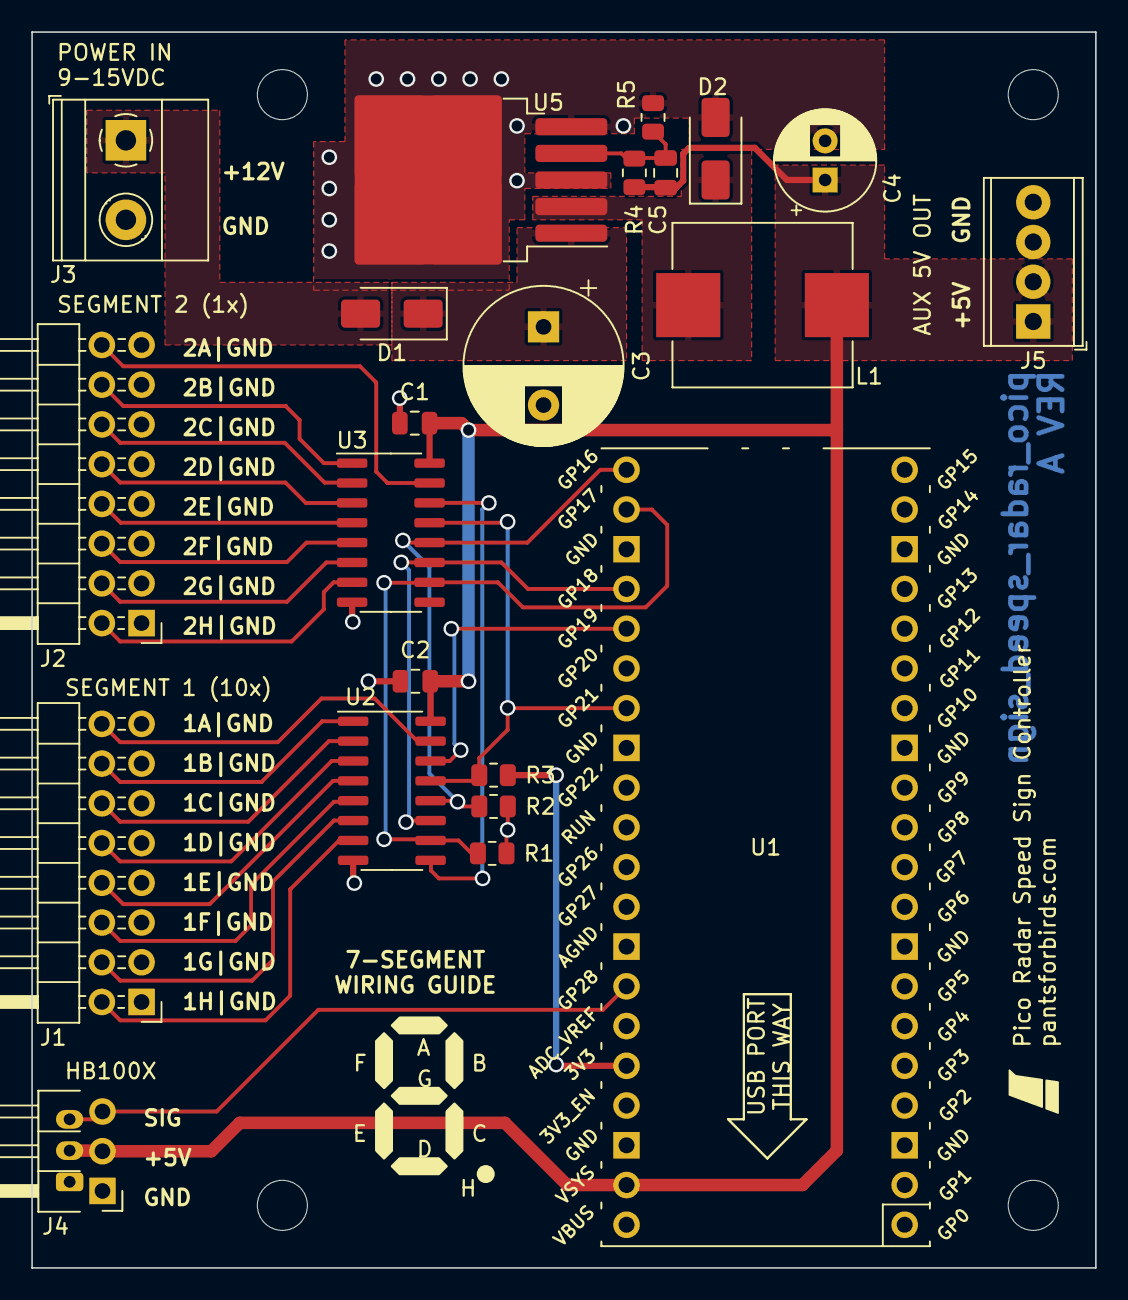
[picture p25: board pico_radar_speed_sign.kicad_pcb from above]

Board: 2 copper layers, 68.0 x 79.0 mm, 29 parts (1 on the bottom side), 30 nets.

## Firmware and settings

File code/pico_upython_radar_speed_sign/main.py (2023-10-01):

from machine import SPI, Pin
from bigass_7_segment import Bigass7SegmentDisplay
from radar_sensor import HB100
from demo_display import DemoDisplay
import utime

SOFTWARE_VERSION = "0.2.0"

DEMO_MODE = False

DIGITS_SPI_PORT = 0
DIGITS_SPI_MOSI_PIN = 19
DIGITS_SPI_SCK_PIN = 18
DIGITS_SPI_SRCLR_PIN = 17
DIGITS_RCLK_PIN = 16
DIGITS_OE_PIN = 21 # active low

DISPLAY_NUM_DIGITS = 2

RADAR_PIN = 28

BRIGHTNESS_CHANGE_PIN = 0
BRIGHTNESS_CHANGE_DEBOUNCE_MS = 500
BRIGHTNESS_VALUES = [1.0, 0.5, 0.1]

def main():
    print(f"Pico Radar Speed Sign {SOFTWARE_VERSION}")
    print("pantsforbirds.com")

    # Initialize the SPI peripheral to talk to the shift registers.
    digits_spi = SPI(
        DIGITS_SPI_PORT,
        baudrate=57600,
        polarity=1,
        phase=1,
        bits=8,
        firstbit=SPI.MSB,
        sck=Pin(DIGITS_SPI_SCK_PIN, Pin.OUT),
        mosi=Pin(DIGITS_SPI_MOSI_PIN, Pin.OUT)
    )

    # Start up the 7-segment display driver.
    display = Bigass7SegmentDisplay(DISPLAY_NUM_DIGITS, digits_spi, DIGITS_SPI_SRCLR_PIN, DIGITS_RCLK_PIN, DIGITS_OE_PIN)
    display.begin()

    # Start up the ISR for the HB100 radar.
    hb100 = HB100()
    radar_pin = Pin(RADAR_PIN, mode=Pin.IN)
    def rising_edge_isr_sorter(pin):
        if pin == radar_pin:
            # print("hi")
            hb100.rising_edge_isr()
    radar_pin.irq(trigger=Pin.IRQ_FALLING, handler=rising_edge_isr_sorter)

    brightness_change_pin = Pin(BRIGHTNESS_CHANGE_PIN, Pin.IN, Pin.PULL_UP)
    brightness_change_debounce_timestamp_ms = utime.ticks_ms()
    brightness_index = 0

    demo = DemoDisplay(display, hb100)
    if DEMO_MODE:
        demo.begin()

    # display_value = 0
    while(True):
        if not brightness_change_pin.value() and utime.ticks_ms() > brightness_change_debounce_timestamp_ms:
            brightness_change_debounce_timestamp_ms = utime.ticks_ms() + BRIGHTNESS_CHANGE_DEBOUNCE_MS
            brightness_index += 1
            if brightness_index >= len(BRIGHTNESS_VALUES):
                brightness_index = 0
            display.set_brightness(BRIGHTNESS_VALUES[brightness_index])
        
        if DEMO_MODE:
            demo.update()
            print(f"speed={hb100.get_speed()}")
        else:
            hb100.update()
            speed_str = hb100.get_speed_str()
            display.set_digits(speed_str)
            display.write()

if __name__ == "__main__":
    main()

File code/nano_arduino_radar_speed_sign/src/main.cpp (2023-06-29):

#include <Arduino.h>
#include <SPI.h>
#include <Wire.h>
#include <LiquidCrystal_I2C.h>
#include <ClickEncoder.h>
#include <EEPROM.h>
#include <TimerOne.h>

#include "seven_seg.hh"
#include "hb100.hh"

#define RADAR_PIN 2

#define LCD_ADDRESS 0x27
#define LCD_WIDTH_CHARS 16
#define LCD_HEIGHT_LINES 2

#define ENCODER_PIN_A A1
#define ENCODER_PIN_B A0
#define ENCODER_PIN_BTN A2
#define ENCODER_STEPS_PER_NOTCH 1


volatile uint32_t last_pulse_us = micros(); // [ms] time of last radar pulse
volatile uint32_t last_pulse_period = 0; // [ms] time between last two falling edges from radar

LiquidCrystal_I2C lcd(LCD_ADDRESS, LCD_WIDTH_CHARS, LCD_HEIGHT_LINES);
ClickEncoder* encoder;

SevenSeg seven_seg; // 7-segment display
HB100 hb100; // radar

void timer1_isr() {
  encoder->service();
}

/**
 * Interrupt handler that triggers on falling pulses from HB100 radar
 **/
void radar_isr() {
  hb100.last_pulse_period = micros() - hb100.last_pulse_us;
  hb100.last_pulse_us = micros();
}

void setup() {
  Serial.begin(9600);

  // Initialize radar.
  pinMode(RADAR_PIN, INPUT);
  attachInterrupt(digitalPinToInterrupt(RADAR_PIN), radar_isr, FALLING);

  // Initialize 7-segment display.
  seven_seg.init();

  // Initialize LCD.
  lcd.init(); // initialize the lcd
	lcd.backlight();
	lcd.setCursor(0,0);
  lcd.clear();

  // Initialize encoder.
  encoder = new ClickEncoder(ENCODER_PIN_A, ENCODER_PIN_B, ENCODER_PIN_BTN, ENCODER_STEPS_PER_NOTCH);
  Timer1.initialize(500);
	Timer1.attachInterrupt(timer1_isr);
}

void loop() {
  // put your main code here, to run repeatedly:
  uint16_t transfer_value = 0;
  while (true) {
    transfer_value = hb100.calc_speed();
    // Serial.print("HB100 last pulse period: ");
    // Serial.println(hb100.last_pulse_period);
    // Serial.print("Calculated speed: ");
    Serial.print(hb100.last_pulse_period);
    Serial.print("    ");
    Serial.println(hb100.calc_speed());
    seven_seg.write(hb100.calc_speed());
    delay(10);
    // transfer_value++;
    // if (transfer_value > 99) {
    //   transfer_value = 0;
    // }
  }
}

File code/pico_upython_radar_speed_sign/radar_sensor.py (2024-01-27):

from machine import Pin
import utime

class HB100:
    LOW_PASS_FILTER_WEIGHT = 1.0 # 1.0 = no filtering
    HOLD_INTERVAL_MS = 500
    SPEED_BUFFER_SIZE = 10
    SPEED_BUFFER_SAMPLE_INTERVAL_MS = 10

    class SpeedFilterMode:
        LOW_PASS = 0
        BUFFER_MAX = 1

    def __init__(self):
        self.last_rising_edge_timestamp_us = utime.ticks_us()
        self.last_pulse_period_us = 1000000 # default to very low speed
        self.speed = 0
        self.hold_end_timestamp_ms = utime.ticks_ms()

        self.speed_filter_mode = self.SpeedFilterMode.BUFFER_MAX
        self.speed_buffer = [0.0]*self.SPEED_BUFFER_SIZE
        self.speed_buffer_index = 0
        self.speed_buffer_prev_index = self.SPEED_BUFFER_SIZE-1
        self.speed_buffer_next_sample_timestamp_ms = 0
    
    def increment_speed_buffer_index(self, index):
        """
        Helper function for wrapping indices on the speed buffer.
        """
        if index >= len(self.speed_buffer)-1:
            return 0
        return index + 1

    def rising_edge_isr(self):
        """
        Interrupt service routine for rising edge on radar pin.
        """
        timestamp_us = utime.ticks_us()
        self.last_pulse_period_us = timestamp_us - self.last_rising_edge_timestamp_us
        self.last_rising_edge_timestamp_us = timestamp_us

        self.hold_end_timestamp_ms = utime.ticks_ms() + self.HOLD_INTERVAL_MS # fresh signal delays blank

        if self.last_pulse_period_us == 0:
            self.speed = 0 # prevent divide by zero
        else:
            new_speed = 31360 / self.last_pulse_period_us # V = Fd / 31.36, Fd = 1 / last_pulse_period[s]
            if self.speed_filter_mode == self.SpeedFilterMode.LOW_PASS:
                self.speed = new_speed * self.LOW_PASS_FILTER_WEIGHT + (1 - self.LOW_PASS_FILTER_WEIGHT)*self.speed    
            elif self.speed_filter_mode == self.SpeedFilterMode.BUFFER_MAX:
                sample_timestamp = utime.ticks_ms()
                if sample_timestamp < self.speed_buffer_next_sample_timestamp_ms:
                    return # limit buffer updates so that faster speeds don't fall out of the buffer too quickly
                self.speed_buffer[self.speed_buffer_index] = new_speed * self.LOW_PASS_FILTER_WEIGHT + (1 - self.LOW_PASS_FILTER_WEIGHT)*self.speed_buffer[self.speed_buffer_prev_index]
                self.speed_buffer_next_sample_timestamp_ms = sample_timestamp + self.SPEED_BUFFER_SAMPLE_INTERVAL_MS
                self.speed_buffer_index = self.increment_speed_buffer_index(self.speed_buffer_index)
                self.speed_buffer_prev_index = self.increment_speed_buffer_index(self.speed_buffer_prev_index)

                self.speed = max(self.speed_buffer)

    def update(self):
        """
        Called frequently to update filters and holds.
        """
        if utime.ticks_ms() >= self.hold_end_timestamp_ms:
            self.speed = 0
            self.speed_buffer = [0] * self.SPEED_BUFFER_SIZE


    def get_speed(self):
        return self.speed
    
    def get_speed_str(self):
        """
        Return a nicely formatted string with an integer speed value in mph, with blanking
        for zero values.
        """
        speed = round(self.get_speed())
        if speed == 0:
            return "  "
        else:
            return str(speed)

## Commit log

2020-10-28 Working version
    [bigass_7_segment-B_Cu.gbr, bigass_7_segment-B_Mask.gbr, bigass_7_segment-B_Paste.gbr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]
2020-11-01 Fix issues with higher speeds
    [hb100.cpp, main.cpp]
2023-06-29 Brief attempt to use BJTs instead of 2N7002
    [bigass_7_segment.kicad_sch]
2023-06-30 Bigass 7 segment display rev B
    [bigass_7_segment-B_Cu.gbr, bigass_7_segment-B_Mask.gbr, bigass_7_segment-B_Paste.gbr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]
2023-07-05 First pass at controller board layout
    [design_calculations.xlsx, pico_radar_speed_sign.kicad_pcb, pico_radar_speed_sign.kicad_sch]
2023-07-06 Make Pico controller Rev A
    [pico_radar_speed_sign-B_Cu.gbr, pico_radar_speed_sign-B_Mask.gbr, pico_radar_speed_sign-B_Paste.gbr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]
2023-07-14 Add demo mode to display code
    [bigass_7_segment-pad_locations.dxf, bigass_7_segment.kicad_pcb, bigass_7_segment.kicad_sch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]
2023-09-04 Make Rev C of segen seg, update README
    [bigass_7_segment-B_Cu.gbr, bigass_7_segment-B_Mask.gbr, bigass_7_segment-B_Paste.gbr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]
2023-10-01 Update low pass filter and buffer code, README
    * Low pass filter implemented on speed buffer.
    * Speed buffer update interval added so that higher speeds (with more frequent rising edges) don't get knocked off the buffer too quickly.
    * README updated with software update instructions.
    [design_calculations.xlsx, hb100_folded_horn_assy.SLDASM, hb100_formed_horn_assy.SLDASM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]
2024-01-22 Add PCB horn antenna
    [amplifier_pcb_outline.DXF, hb100_amplifier.kicad_pcb, hb100_amplifier.kicad_sch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]
2024-01-27 Add CPP firmware folder
    [amplifier_pcb_outline.DXF, front_bracket.SLDPRT, hb100_amplifier.kicad_pcb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]
2024-02-06 Get FFTs working but lots of spectral leakage
    [hb100.cpp, main.cpp, plot_fft.py]
2024-02-21 Production files for extended range horn
    [back_inner_bracket^hb100_pcb_horn_assy.3mf, back_inner_bracket^hb100_pcb_horn_assy.STL, back_outer_bracket^hb100_pcb_horn_assy.STL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]
2024-03-19 Update mech assembly and LTSpice sim
    [back_inner_bracket^hb100_pcb_horn_assy.STL]
2024-03-20 Update radar_util
    * Add velocity extraction.
    * Fix arrow positions.
    * Drop extra samples to hopefully fix issue with buffer lag.
    [radar_util.py]
2024-05-02 Ignore kicad backups
